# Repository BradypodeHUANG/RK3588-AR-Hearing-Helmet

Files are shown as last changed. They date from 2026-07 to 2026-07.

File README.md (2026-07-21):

# -RK3588-
2026嵌赛芯片应用赛道瑞芯微赛题参赛作品，本项目专为听障人群打造智能AR户外辅助头盔。系统以基于RK3588的ELF2边缘节点为算力核心，通过低功耗蓝牙与专属手机App无缝交互，实时获取定制导航流。视觉渲染上，系统深度调用底层Mali-G610 GPU硬件加速与Vulkan图形接口，配合NanoVG引擎在双目AR模组上高帧率绘制全景HUD路书。感知交互层则全面释放内置6 TOPS NPU算力，本地部署AI大模型实现环境声音方位识别与视觉预警；同时集成红外摄像与红外补光模组，达成复杂光线下的高精手部追踪与实时手语翻译。项目将跨维度信息彻底“视觉化”，重塑出行安全与沟通独立性。
参赛视频链接：【嵌赛陪跑了，初评未过】https://www.bilibili.com/video/BV1GoNi6BEtV?vd_source=469369b1c468a4abbb477049de3c671e

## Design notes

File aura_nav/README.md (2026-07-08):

# aura_nav

A new Flutter project.

## Getting Started

This project is a starting point for a Flutter application.

A few resources to get you started if this is your first Flutter project:

- [Learn Flutter](https://docs.flutter.dev/get-started/learn-flutter)
- [Write your first Flutter app](https://docs.flutter.dev/get-started/codelab)
- [Flutter learning resources](https://docs.flutter.dev/reference/learning-resources)

For help getting started with Flutter development, view the
[online documentation](https://docs.flutter.dev/), which offers tutorials,
samples, guidance on mobile development, and a full API reference.

## Android APK build on China mainland networks

This project already points Gradle at domestic mirrors for most Android
dependencies. To avoid Flutter and pub still reaching slow overseas sources,
use the helper script below when building an APK:

```powershell
powershell -ExecutionPolicy Bypass -File .\tools\build_apk_cn.ps1 -Mode arm64
```

Useful modes:

- `arm64`: fastest for most modern Android phones.
- `universal`: one APK for mixed device architectures, but slower and larger.
- `split-per-abi`: generates multiple smaller APK files, one per ABI.

If you only want to warm caches first:

```powershell
powershell -ExecutionPolicy Bypass -File .\tools\build_apk_cn.ps1 -PrepareOnly
```

APK output directory:

```text
build\app\outputs\flutter-apk
```

Notes:

- The first release build can still take a long time because Flutter release
  builds do AOT compilation, resource processing, and native packaging.
- The current Android release config still uses the debug signing key, so the
  APK can be installed directly on other phones, but a custom release keystore
  should be configured before formal distribution.

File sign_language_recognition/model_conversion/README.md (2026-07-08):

# 模型转换 (ONNX → RKNN)

把训练好的 `best_model.onnx` 转换成 RK3588 NPU 用的 `.rknn`，并对照训练流程
验证转换无误。独立于 `rk3588_deploy/`（部署代码），这里只管"把模型变成 .rknn"。

## 预处理版本（2026-06-06 起）

`dataset.py` 的预处理改版：直接读**原始绝对坐标** `tracking.csv`（不再读派生的
`tracking_relative_to_right_palm.csv`），在 `load_session` 内部把**两只手统一**
锚定到右手首帧 palm 坐标系，并丢弃右手首次出现之前的帧。

- `gen_golden.py` 已同步改用 `tracking.csv`（否则会双重坐标变换）。
- **右手处理与旧版数学等价；左手坐标系完全不同**（旧版相对自己手掌、新版相对右手）。
  因此模型**必须用新版 dataset.py 重新训练**后再转换，否则双手类（如「忙」）会预测错乱。
- C 端实时采集（若仍维护）也需同步成"两手统一锚定到右手 palm"，否则与训练分布不一致。

## 当前模型（第三版，15 类）

- 输入 `[1, 6, 60, 26, 2]`（6 通道 pos+vel、60 帧、26 节点、2 手）—— 历代不变
- 输出 `[1, 15]` —— **15 类**（类别顺序 = 数据集目录名的 `sorted()`）：

  | 索引 | 类别 | 索引 | 类别 | 索引 | 类别 |
  |---|---|---|---|---|---|
  | 0 | 伤心 | 5 | 大家好 | 10 | 感动 |
  | 1 | 你好 | 6 | 害怕 | 11 | 未知 |
  | 2 | 去 | 7 | 工作 | 12 | 来 |
  | 3 | 吃 | 8 | 开心 | 13 | 现在 |
  | 4 | 名字 | 9 | 忙 | 14 | 看 |

  > 注意：加入新类后，`sorted()` 顺序整体重排（新类按拼音/笔画插进中间），
  > 索引和上一版不同。部署端标签表务必按 `output/labels.txt` 全量更新。

## opset 重导出（第三版必做）

第三版的 `best_model.onnx` 是 PyTorch 2.12 的新 dynamo 导出器在 **opset 18**
下导出的（70 节点、权重存在 `best_model.onnx.data` 外部文件），它会触发
RKNN-Toolkit 2.3.2 常量折叠器的 bug（`MatMul` 与邻接矩阵相乘时 shape 广播报错），
**无法直接转换**。

解决：用 `reexport_onnx.py` 从 `best_model.pth` 以 **opset 12 + 经典 TorchScript
导出器**重新导出（产出 `best_model_opset12.onnx`，82 节点、单文件、与前两版同构）。
`gen_golden.py` 和 `convert.py` 都已指向这个重导出文件。

> 若以后训练侧把导出 opset 改回 12（修改 `train.py` 的 `opset_version`），
> 可直接用 `best_model.onnx`，跳过重导出这步。

## 用法

在 `RKNN-Toolkit-2.3.2` conda 环境里运行（含 numpy/scipy/onnxruntime/rknn-toolkit2/torch）：

```bash
conda activate RKNN-Toolkit-2.3.2
cd model_conversion

# 0) 从 .pth 重导出 opset-12 ONNX (绕过 RKNN 2.3.2 的 opset18 折叠 bug)
python reexport_onnx.py

# 1) 生成 golden 参照 (复用 dataset.py 预处理 + ONNX 推理)，每类各一条样本
python gen_golden.py

# 2) ONNX → RKNN (rk3588, fp16 非量化) + 用 golden 在模拟器上校验
python convert.py
```

产物在 `output/`：

```
output/
├── sign_rk3588.rknn        转换好的 NPU 模型
├── labels.txt              9 类标签 (索引 / 汉字)，供部署端核对
└── golden/<类别>/          每类的 golden_input.bin + golden_logits.txt
```

## 验证标准

`convert.py` 对每个 golden 样本比较 ONNX 与 RKNN 模拟器输出：
- 余弦相似度 > 0.999
- argmax 一致

全部通过才算转换成功。

## 部署

把 `output/sign_rk3588.rknn` 拷到 `rk3588_deploy/model/sign_rk3588.rknn`。
类别数变化时，部署端 `src/labels.c` 也要同步更新成 9 类（见 `output/labels.txt`）。

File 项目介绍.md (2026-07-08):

# Aura AR 项目介绍

## 1. 项目概览

这是一个围绕 AR 头显展开的多模态交互项目，核心目标不是单点功能演示，而是把光学显示、底层渲染、空间交互、导航、语音、声音感知和后视辅助整合到同一套低延迟系统中。项目主控程序为 `ar_app1_hud.cpp`，运行在 ELF2 / RK3588 侧，配套包含手语识别、导航通信、语音识别、离线语音合成、声音雷达和后置摄像头等模块。

从系统结构看，这个项目有几个非常鲜明的特点：

- 显示链路不是跑在传统桌面窗口之上，而是直接深入到底层 DRM / GBM / EGL / OpenGL ES 渲染栈，以减少不必要的桌面合成开销。
- 光学链路不是“把画面画出来就结束”，而是必须先对近眼光学畸变做反向校正，再解决双目汇聚与双目视差问题，最后才能在真实佩戴状态下得到自然画面。
- 输入链路不是单一交互，而是同时接入了 Ultraleap 双目红外手部跟踪、手机导航、8 路麦克风声音感知、后置摄像头和语音识别/语音播报。
- 模型部署强调本地化、低时延与离线能力，STT/TTS 接入 sherpa-onnx，手语模型和声音分类模型接入 RKNN / RKNNLite，充分利用 RK3588 平台的边缘推理能力。

## 2. 系统总体架构

项目可以理解为一个“统一 AR 运行时”：

1. `ar_app1_hud.cpp` 负责主显示、状态机、应用切换、底层渲染和多线程调度。
2. 光学部分通过 `calibration.json` 中的标定参数构建双目畸变网格，将逻辑 UI 映射到真实可视平面。
3. 手语模块由 `ultraleap_rknn_live` 负责采集 Sir170 的 3D 手部骨架并调用 `sign_rk3588.rknn` 做推理。
4. 导航模块由 Flutter 手机 App `aura_nav` 提供路径规划、定位与蓝牙通信，头显侧通过 Bluetooth RFCOMM 接收导航 JSON 数据并绘制 HUD 界面。
5. 语音模块分两部分：`sherpa-onnx-alsa` 负责语音转文字，`sign_translate_tts_service.py` + `sherpa-onnx-offline-tts` 负责离线文字转语音。
6. 声音雷达由 `sound_radar_service.py` 完成采集、分类、定位，并把结果通过本地 TCP 回传给 HUD。
7. 后置摄像头模块通过 V4L2 / OpenCV 取流，再由 HUD 统一合成到骑行模式界面中。

这种架构的优点是：各功能都以独立服务/线程运行，但最终统一汇总到一个近眼渲染和交互系统里，既保证了模块边界清晰，也保证了最终用户体验是一体化的。

## 3. 光学系统与底层显示链路

### 3.1 光学方案：基于 North Star 思路的双目近眼显示

本项目采用的是 North Star 风格的双目近眼光学方案。公开资料中，Project North Star 是一套强调大视场、开放硬件和手部交互结合的 AR 头显设计，核心思想是：

- 使用双目显示系统分别向左右眼送入图像；
- 通过近眼光学结构把显示内容投送到人眼可接受的观察空间；
- 在较大视场下追求更自然的空间叠加感；
- 与手部追踪系统天然结合，强调“看见 + 看懂 + 可交互”。

但这类方案真正落地时，最难的从来不是“把屏幕点亮”，而是“让人眼看到正确画面”。你的项目在这方面实际上已经做到了比较完整的一条链路。

### 3.2 难点一：镜片本身存在畸变，必须先做反畸变校正

近眼光学系统的第一大难点，是镜片/组合光路自身就会引入明显几何畸变。直接把 2D UI 生硬绘制到面板上，经过镜片后，人眼看到的图像会变形，文字和图标会扭曲，双目情况下还会进一步放大不适感。

在 `ar_app1_hud.cpp` 中，这一问题是通过标定数据驱动的“每眼 UV 反畸变网格”来解决的。关键实现包括：

- 读取 `calibration.json`；
- 解析 `left_uv_to_rect_x / left_uv_to_rect_y / right_uv_to_rect_x / right_uv_to_rect_y` 等多项式系数；
- 根据每只眼的标定参数生成高密度 distortion mesh；
- 在渲染阶段通过网格顶点的 `u,v` 重映射，把逻辑画面扭成“经过镜片后看起来才正常”的图像。

从代码逻辑看，这套做法不是简单的平面仿射变换，而是基于标定多项式对每个采样点的光线进行重建，再计算其落到显示平面上的采样坐标。也就是说，你实际做的是“先从人眼观察空间反推到显示空间”的校正思路。

### 3.3 难点二：双目汇聚、双目视差与校正数据耦合

第二个难点比反畸变更棘手：左右眼不仅各自有畸变，还要在矫正之后实现稳定的双目汇聚。

你的代码里并不是把左右眼简单复制一份 UI，而是进一步引入了：

- 左右眼不同的光学平面角度；
- 左右眼各自的 `eye_origin_x_mm`；
- 倾斜显示平面的几何求交；
- 面板剪切量 `panel_shear`；
- 可调的 `g_symmetric_shear` 运行时参数。

这意味着双目汇聚在你的系统中不是“后处理贴个偏移”这么简单，而是把以下几件事耦合在一起考虑：

1. 标定得到的左右眼 UV 校正数据；
2. 观察光线与倾斜显示面的真实相交关系；
3. 左右眼对称但方向相反的 plane angle / panel shear；
4. 为了佩戴体验而保留的运行时微调能力。

换句话说，你的双目汇聚并不是单纯的几何偏移，而是把“畸变校正”和“会聚调参”统一到一个渲染数学模型里。这正是近眼 AR 系统最关键也最难做好的一步。

### 3.4 UV 平面校正与可调收敛

代码中 `getEyeAdjustments()`、`intersectTiltedPlane()`、`computePanelUv()` 和 `generateDistortionMeshesHudFromCalibration()` 这几部分串起来后，形成了一条完整的链路：

- 先由标定多项式恢复每只眼的视线方向；
- 再与倾斜显示平面求交；
- 再把交点映射回面板局部坐标；
- 最后得到真正用于采样的 `src_u/src_v`。

同时，`g_symmetric_shear` 可以在运行时修改，一旦参数变化，双目 distortion mesh 会重新生成。这让系统具备了“调参即更新光学校正”的能力，非常适合真实头显调机阶段使用。

### 3.5 驱动层细节：绕开桌面系统，直接操作底层硬件

为了追求更高性能，这个项目关闭桌面系统，直接从底层图形硬件进行操作。主程序中可见：

- 直接访问 `/dev/dri/card0`；
- 使用 DRM / GBM 完成缓冲区管理；
- 使用 EGL / GLES2 进行渲染；
- 使用 NanoVG 完成高质量矢量 UI 绘制。

这么做的价值很明确：

- 避免桌面合成器带来的额外延迟；
- 降低图像链路抖动；
- 更容易把光学校正网格、双目渲染和 HUD UI 合在一起管理；
- 更适合面向 AR 头显的固定功能运行时。

你在 UI 层选择 NanoVG 也很合理。对这种需要大量线条、圆角、描边、渐变、平滑动画和可读文字的 AR HUD 来说，NanoVG 在抗锯齿和精细轮廓表现上明显优于“把 OpenCV 当 UI 库来画”的方案。

## 4. 手语识别功能

### 4.1 硬件基础：Ultraleap Sir170 双目红外相机

手语识别部分使用的是 Ultraleap Sir170 双目红外相机。它的优势不是普通 RGB 摄像头能替代的：

- 天然面向近距离手部交互；
- 可以实时输出高精度 3D 手部骨架；
- 在毫米级空间尺度上提供稳定的手部关节点坐标；
- 对近眼交互特别友好，因为它不是只做 2D 检测，而是直接提供 3D 重建结果。

在你的系统里，Sir170 不只是“看见手”，而是为后续手语识别模型直接提供骨架级别的结构化输入。

### 4.2 手语识别后端与模型

手语识别实际由 `ultraleap_rknn_live` 执行，它把 LeapC 采集到的骨架数据预处理后送入 RK3588 NPU 运行 `sign_rk3588.rknn`。

从代码可以读出，这个模型的输入结构是：

- 2 只手；
- 26 个关节点；
- 每点 3 个空间坐标；
- 额外拼接位置与速度，共 6 个输入通道；
- 时间维统一重采样到 60 帧；
- 最终张量为 `[1, 6, 60, 26, 2]`。

这说明你的模型不是做“单帧静态姿态分类”，而是典型的时序手语识别。它既看空间结构，也看动作随时间的演化。

### 4.3 识别流程

`ultraleap_rknn_live` 的流程很有代表性：

1. 连接 Ultraleap 设备；
2. 使用 `eLeapTrackingMode_HMD` 进入头显跟踪模式；
3. 持续接收手部帧；
4. 直到第一只右手出现后，开始建立一个手势窗口；
5. 以第一帧右手掌心为锚点，对后续节点做相对化处理；
6. 当 0.3 秒内没有新的手帧时，关闭当前手势窗口；
7. 把窗口序列整理成 `[1,6,60,26,2]` 输入；
8. 交给 RKNN 模型完成分类。

这种“以右手起始掌心为锚点”的做法很重要，因为它把用户在不同空间位置做出的手势变成了更稳定的相对动作模式，降低了绝对位姿变化对分类结果的影响。

### 4.4 模型类别

从 `labels.c` 可以读出当前模型是一个 15 类手语模型，包含如下拼音标签：

- `shangxin`
- `nihao`
- `qu`
- `chi`
- `mingzi`
- `dajiahao`
- `haipa`
- `gongzuo`
- `kaixin`
- `mang`
- `gandong`
- `unknown`
- `lai`
- `xianzai`
- `kan`

也就是说，这个模型已经不只是“左右挥手/简单手势”的演示，而是具备基础词汇表达能力，可以进一步与听障交流和语音播报模块联动。

### 4.5 与 TTS 的耦合

在你的 AR 系统里，手语识别不是一个孤立模块。识别结果会进一步送入 TTS 线程，使用本地离线语音合成播报出来。这样一来，Sir170 + 手语模型 + TTS 共同构成了完整的“手语输入 -> 语音输出”链路，直接服务听障交流场景。

## 5. 导航功能

### 5.1 头显侧导航设计

HUD 端导航不是传统 2D 地图平移，而是专门为近眼显示设计的简洁导航界面。代码中可以看到它包含多个互相协同的视觉层：

- 前方主引导路径；
- 蓝色流光式路线高亮；
- 车辆/朝向 puck；
- 小地图总览；
- 转向箭头；
- 剩余距离进度条；
- 到达态和待机态切换动画。

这套 UI 的重点不是堆信息，而是减少认知负担。近眼显示的面积和注意力窗口都很有限，因此真正有用的是：

- 把“下一步动作”放到最醒目位置；
- 把“全局路线”做成辅助；
- 把“剩余距离”和“转弯距离”做成低认知负担数字信息；
- 用平滑过渡和方向滤波避免箭头乱跳、路径抖动和方向突变。

代码里对导航平滑做了多层处理：

- 路径只在 `full_path` 更新时重建；
- 小车朝向使用 `smooth_heading` 逐步收敛到 `raw_heading`；
- 当前显示距离与转向距离使用 display 变量做过渡；
- UI 状态从 `STANDBY -> TRANSITION_IN -> NAVIGATING -> ARRIVED` 分层切换。

这让界面不是“硬切换的信息面板”，而更像一个持续、平稳、可读的 AR 导航仪表。

### 5.2 手机 App：导航系统真正的智能核心

虽然头显侧负责最终显示，但从工程量和逻辑复杂度来看，手机端 `D:\Flutter_projects\aura_nav` 才是导航功能的智能核心，值得重点介绍。

这个 App 主要负责四件事：

1. 定位与定位稳态管理；
2. 高德路线规划；
3. 地图搜索、选点和路线缓存；
4. 通过蓝牙把导航状态持续同步给头显。

### 5.3 Flutter App 的定位与路径规划逻辑

App 使用了：

- `amap_flutter_map` / `amap_flutter_base`：地图显示和基础地图能力；
- `Geolocator`：高精度位置获取；
- `permission_handler`：Android 权限处理；
- 自定义 `BluetoothTransport`：蓝牙 MethodChannel 通道。

定位方面，它不是只读一次位置，而是做了“持续位置流 + 定期强制刷新”的双通路设计：

- `LocationAccuracy.bestForNavigation`；
- `distanceFilter = 2` 米；
- Android 侧强制导航级定位；
- 周期性刷新当前位置；
- 当有新位置且正在导航时，触发路径更新逻辑。

路径规划方面，它会请求高德骑行路径接口：

- 根据起点和目标点获取骑行路径；
- 对每个导航 step 解析 `polyline`；
- 合并成完整路径；
- 计算每个 step 的起止累计距离；
- 建立 `_CachedRoute` 供后续快速投影和重路由使用。

### 5.4 路径投影与重路由机制

这部分是手机端最值得强调的地方之一。

App 并不是每次位置更新都粗暴重新请求路线，而是先做几何投影：

- 把当前位置投影到当前路线折线段上；
- 计算当前已经走过的进度 `progressMeters`；
- 计算当前位置到路线的最短距离 `distanceToRouteMeters`；
- 如果偏离路线大于 45 米且连续两次命中，则触发重路由。

这套机制有两个优点：

1. 减少无意义的网络请求和路线抖动；
2. 让 HUD 收到的“下一步动作 / 剩余距离 / 总距离”更稳定。

### 5.5 蓝牙交互：手机与头显的桥梁

手机端蓝牙层由 `bluetooth_transport.dart` 封装，通过 MethodChannel `aura_nav/bluetooth` 调用 Android 原生蓝牙能力。App 支持：

- 判断设备是否支持蓝牙；
- 判断蓝牙是否开启；
- 获取已配对设备列表；
- 用户选择 ELF2 板端蓝牙地址；
- 连接 / 断开；
- 向头显发送 JSON 负载。

头显端则在 `ar_app1_hud.cpp` 中开启 Bluetooth RFCOMM 服务，注册 SDP 服务描述，并在 socket 中按行接收 JSON。这样，手机端就能把如下信息同步给头显：

- 当前经纬度；
- 目的地经纬度；
- 目的地名称；
- 下一步动作；
- 到下一步动作的距离；
- 剩余距离；
- 总距离；
- 全路径 polyline。

手机端还做了一个很实际的优化：相同 payload 不重复发送。这减少了蓝牙带宽浪费，也降低了 HUD 端不必要的重复解析。

### 5.6 为什么手机端值得重点介绍

导航能力真正复杂的地方，从来不在“把箭头画出来”，而在：

- 如何稳定拿到高质量定位；
- 如何做路线缓存与投影；
- 如何判断偏航；
- 如何在网络与蓝牙状态波动时仍维持一个稳定、低抖动的导航体验。

`aura_nav` 在这些点上已经形成了较完整的工程实现，所以它不仅是一个配套 App，更是整个导航子系统的上游控制中心。

## 6. 后置摄像头功能

后置摄像头模块的目标很明确：给骑行/通勤场景提供实时后视信息，减少用户回头成本，提高态势感知能力。

从当前检查到的 `ar_app1_hud.cpp` 来看，默认参数是：

- 设备：`/dev/video21`
- 分辨率：`640 x 480`
- 默认采集帧率：`60 fps`
- 显示宽度：720 像素等效布局

代码本身已经体现出这是一个面向高帧率、低缓冲的设计：

- 优先使用 V4L2 打开摄像头；
- 设置 `CAP_PROP_BUFFERSIZE = 1`；
- 以独立线程持续采集；
- 在骑行模式中与导航、声音雷达一起组合显示。

你提到项目侧后置摄像头能达到 90 fps，这说明实际部署时硬件链路和驱动配置可能已经进入更高刷新模式。就我检查到的这份 `ar_app1_hud.cpp` 而言，当前默认值是 60 fps；如果板端实测已达 90 fps，那么说明真实运行配置比当前源码默认值更激进，这也是非常合理的工程演化方向。

广角后视对于 AR 骑行系统特别重要，因为它把“后方大范围感知”压缩成了一个可随时扫视的小窗口，和声音雷达一起，可以形成视觉 + 听觉的双模态安全辅助。

## 7. 声音转文字与文字转语音

### 7.1 使用 sherpa-onnx 生态进行本地化部署

语音相关能力建立在 sherpa-onnx 生态之上。你给出的 STT 模型来源页是：

- RK3588 流式双语语音识别模型页：
  <https://k2-fsa.github.io/sherpa/onnx/rknn/models.html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>

在工程里，这套能力拆成了两部分：

- 语音转文字：`sherpa-onnx-alsa` + RK3588 Zipformer bilingual zh-en streaming small 模型；
- 文字转语音：`sherpa-onnx-offline-tts` / `sign_translate_tts_service.py` + Matcha zh-baker 声学模型 + Vocos vocoder。

所以更准确地说：STT 和 TTS 都来自 sherpa-onnx 这一开源项目生态，但使用的是不同的子模型链路。

### 7.2 语音转文字（STT）

STT 侧使用的模型文件包括：

- `encoder.rknn`
- `decoder.rknn`
- `joiner.rknn`
- `tokens.txt`

这类 Zipformer 架构模型的优势在于：

- 流式识别能力强，适合边说边出字；
- 双语中英场景适配更灵活；
- 通过 RKNN 部署到 RK3588 NPU，时延、功耗和离线能力都更适合 AR 设备；
- 不依赖云端，可降低隐私风险与弱网依赖。

在你的系统中，STT 不是单纯地把日志打印到终端，而是被整合到 `SPEECH TO TEXT` 和 `HEARING ASSIST` 模式里，为听障交流和骑行场景提供实时字幕能力。

### 7.3 文字转语音（TTS）

TTS 侧使用：

- `model-steps-3.onnx`
- `vocos-22khz-univ.onnx`
- `lexicon.txt`
- `tokens.txt`
- `phone.fst / date.fst / number.fst`

它在你的项目里有两条运行路径：

1. 通过 `sign_translate_tts_service.py` 驻留式常驻服务完成请求-响应式合成；
2. 若常驻服务不可用，则回退到 `sherpa-onnx-offline-tts` 命令行方式直接合成。

这套设计很成熟，体现了几个很有价值的工程优化：

- **常驻服务预热**：避免第一次调用时模型冷启动太慢；
- **缓存机制**：同一句话生成后的 wav 直接命中缓存；
- **重复播报去重**：短时间内不重复读相同文本；
- **多设备播放尝试**：自动检测 ALSA 播放设备，降低部署时音频设备不一致带来的问题。

### 7.4 接入 AR 项目后的改进点

相比把 sherpa-onnx 当一个独立 demo 使用，你在 AR 项目里做了更贴近产品化的适配：

- STT 和 TTS 都被纳入状态机统一管理；
- TTS 既服务语音播报，也服务手语识别结果输出；
- 听障交流模式下，手语识别文本和语音识别文本可以同时进入统一 UI；
- 通过缓存、常驻服务和线程化监督机制，尽量压缩了模型调用时延；
- 全链路保持离线运行，适合移动 AR 设备。

## 8. 声音雷达功能

### 8.1 8 路麦克风 + 声音分类 + 声源定位

声音雷达是这个项目里非常有特色的一部分。它不是简单的“拾音 + 阈值触发”，而是把：

- 8 路麦克风阵列采集；
- 声音事件分类；
- 声源方向估计；
- 时间平滑与异常抑制；
- HUD 方向可视化

完整地串成了一条链路。

### 8.2 声音分类模型

`sound_radar_service.py` 中使用的分类模型是：

- `yamnet_rk3588_int8.rknn`
- `yamnet_class_map.csv`

它基于 RKNNLite 在 RK3588 上运行。输入端会：

- 从 8 路麦克风中取分类专用通道；
- 重采样到 16 kHz；
- 构建 log-mel spectrogram；
- 生成 `(1, 96, 64, 1)` 形状的输入；
- 调用 RKNN 做推理。

在类别策略上，项目没有试图识别“所有声音”，而是聚焦真正对骑行/出行安全有价值的目标：

- 车喇叭相关（horn / honk / truck horn / toot 等）
- horn-like 警示声（buzzer / alarm / siren / bell / ringtone 等）
- 狗叫相关（bark / howl / growl / whimper 等）

对应阈值在代码里分开设置，例如：

- horn：0.20
- horn-like：0.12
- dog：0.30

这说明你在工程上做了“任务定制化裁剪”，而不是照搬通用音频分类器输出。

### 8.3 声音定位算法：不是黑盒，而是清晰的信号处理链

声音定位部分，代码中能读出一条相当完整的 DOA（Direction of Arrival）估计流程。

核心思路包括：

- 采样率 48 kHz，8 通道采集；
- 使用外圈 6 个通道做方向估计；
- 对信号做 300~4000 Hz 带通；
- 使用 GCC-PHAT 估计通道对时延曲线；
- 使用 SRP-PHAT 在 `-180° ~ 180°`、步长 `2°` 的角度空间内打分；
- 结合多通道几何布局计算最优方向；
- 通过直达声/回声能量比过滤反射干扰；
- 通过时间历史和置信度机制抑制抖动与离群值。

这说明你的声音雷达不是“神经网络一把梭”，而是把经典阵列信号处理与声音分类模型组合起来，形成了“先判别是什么，再估计从哪里来”的双阶段系统。

### 8.4 抗抖动与异常方向过滤

声音定位真正难的是环境反射、瞬时噪声和方向跳变。你的代码在这方面做了不少处理：

- 最近时间窗优先；
- 直达声/回声比过滤；
- 稳定 cluster 才接受；
- 冷启动确认机制；
- 大角度突变时的强跳变确认机制；
- 历史方向平滑与加权更新；
- 输出节流（0.25 秒）。

这几层机制叠加后，最终方向输出不会随着每一帧的瞬时最大值乱跳，而更接近一个“对用户有意义”的稳定方向提示。

### 8.5 HUD 呈现方式

HUD 侧接收到声音雷达事件后，会进一步做 UI 级平滑：

- 每个目标都有 `target_angle_deg` 和 `display_angle_deg`；
- 使用弹簧-阻尼模型推进显示角度；
- 限制角速度上限；
- 随时间衰减显示；
- 根据类别显示不同样式与颜色。

这使声音雷达不只是后台日志，而是一个真正适合 AR 头显展示的空间提示系统。对骑行和步行安全来说，这种“看不见的声音被转成可视方向”非常有价值。

## 9. 项目价值总结

这个项目最有意思的地方，不是某一个单独模型多先进，而是它把多种能力真正整合成了一套 AR 系统：

- 光学侧解决了近眼显示最难的畸变与双目汇聚问题；
- 渲染侧深入到底层硬件，追求低延迟和高效率；
- 交互侧把手语、语音、导航、声音、后视都接入同一显示平台；
- 模型侧充分利用 RK3588 的本地推理能力；
- 工程侧已经明显超出了“功能 demo”的范畴，开始具备产品原型系统的结构特征。

如果把它理解成一句话：这不是“AR 里塞几个功能”，而是在做一套围绕真实使用场景构建的、多模态、低延迟、可离线运行的 AR 交互平台。

## 10. 参考资料

- sherpa-onnx RK3588 流式双语语音识别模型页：<https://k2-fsa.github.io/sherpa/onnx/rknn/models.html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>
- sherpa-onnx TTS 总览：<https://k2-fsa.github.io/sherpa/onnx/tts/index.html>
- sherpa-onnx Matcha TTS 模型页：<https://k2-fsa.github.io/sherpa/onnx/tts/pretrained_models/matcha.html>
- Project North Star 公开背景可参考相关公开报道与开源资料，例如 Wired 对其开放硬件 AR 头显定位的介绍：<https://www.wired.com/beyond-the-beyond/2018/04/leap-motion-augmented-reality-headset>

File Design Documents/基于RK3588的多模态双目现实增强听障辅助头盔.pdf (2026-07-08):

## 基于 RK3588 的多模态双目现实增强听障辅助头盔

摘要

本作品面向听障人群在日常出行、交流沟通和环境感知中的实际需求，

设计并实现了一款基于 RK3588 平台的多模态双目现实增强听障辅助头盔。

系统以 ELF2（RK3588 开发板）作为核心控制与计算平台，结合红外双目

摄像头、后视摄像头、8 通道麦克风阵列、AR 显示模块、蓝牙通信模块、

自制外部按键 PCB、电源模块以及 USB 扬声器等硬件单元，实现了视觉、

语音、手语和导航信息的多模态融合处理。

在感知输入方面，系统通过后视摄像头获取使用者后方环境图像，通过

红外双目摄像头采集手语图像信息，通过 8 通道麦克风阵列采集空间声音

信息，为后续的语音识别、声源定位、声音分类和手语识别提供数据基础。

在核心处理方面，系统利用 RK3588 的 CPU 完成任务调度、数据管理和多

模态融合，利用 NPU 加速手语识别、ASR、TTS 和声音分类等 AI 模型推

理，利用 GPU/VOP 完成 AR 画面渲染与显示输出。在交互输出方面，系统

通过 AR 眼镜镜片实时显示字幕、导航提示、环境提醒和识别结果，并通过

USB 扬声器输出手语翻译语音，实现面向听障用户的增强现实辅助交互。

本作品将多模态感知、边缘 AI 推理、AR 显示和可穿戴结构相结合，

具有实时性强、交互直观、功能集成度高和应用场景明确等特点，可应用于

听障人群日常沟通、户外导航、安全提醒、无障碍辅助交流等场景。通过该

系统，听障用户能够更加直观地获取周围声音、图像和导航信息，从而提升

出行安全性、交流便利性和生活独立性。

第一部分 作品概述

1.1 功能与特性

本作品是一款面向听障用户的智能辅助头盔，主要实现环境感知、语音

转文字、手语识别、语音播报、后方视觉辅助和 AR 信息显示等功能。系统

通过 8 通道麦克风阵列采集周围声音信息，可对语音内容进行识别并转换

为文字，在 AR 眼镜镜片上实时显示，帮助听障用户理解外界语言信息。红

外双目摄像头用于采集手语图像信息，系统通过 AI 模型识别手语动作，并

将识别结果转换为文字或语音输出，实现听障用户与普通人之间的双向辅助

交流。后视摄像头用于采集后方图像信息，辅助用户感知身后环境，提高出

行安全性。手机 APP 可通过蓝牙向头盔端发送导航信息，并接收板端状态

回传。系统具有多模态输入、边缘端实时处理、AR 可视化输出、佩戴式交

互和移动端协同等特点。

1.2 应用领域

本作品主要应用于听障人群的日常生活辅助、户外出行安全、无障碍交

流和智能可穿戴设备等领域。在日常交流场景中，系统能够将外界语音转换

为文字显示，帮助听障用户理解对话内容；在手语交流场景中，系统可识别

用户手语动作并通过语音或文字方式输出，降低听障用户与非手语使用者之

间的沟通障碍。在户外出行场景中，后视摄像头和 AR 显示模块能够辅助用

户感知后方环境和导航信息，提高道路通行安全性。在公共服务、校园、医

院、车站等人流密集场景中，该系统也可作为一种智能无障碍辅助终端，为

听障群体提供实时、直观、便携的环境信息获取方式。该作品还可扩展应用

于工业安全头盔、骑行辅助设备、智能导览系统和多模态人机交互终端等方

向。

1.3 主要技术特点

本作品的主要技术特点体现在多模态感知、边缘 AI 推理、AR 增强显

示和可穿戴系统集成四个方面。首先，系统同时融合了摄像头、麦克风阵列、

手机 APP 和按键 PCB 等多种输入方式，可获取图像、声音、导航和控制

信息。其次，系统基于 RK3588 平台进行本地化推理，利用 NPU 加速手语

识别、ASR、TTS 和声音分类等模型，降低对云端网络的依赖，提高系统响

应速度和隐私安全性。再次，系统采用 AR 显示模块作为主要信息输出方式，

可将字幕、导航、识别结果和环境提示叠加显示在用户视野中，使交互更加

直观。最后，系统将开发板、传感器、电源、AR 显示和外部控制模块集成

到头盔平台中，具备移动佩戴和实际场景使用的可行性。

1.4 主要性能指标

指标项目 | 指标内容 | 指标完成度
主控平台 | ELF2 开发板（RK3588） | 已确定
AI 推理单元 | RK3588 内置 NPU | 已确定
图像输入 | USB 摄像头、红外双目摄 像头 | 已实现
音频输入 | 8 通道麦克风阵列 | 已实现
显示输出 | MIPI-DSI 接口连接 AR 显示模块 | 已实现
音频输出 | USB 扬声器 | 已实现
外部通信方式 | 蓝牙通信，手机 APP 交 互 | 已实现
控制方式 | 自制按键 PCB、串口通信 | 已实现
功能指标 | 语音转文字、手语识别、 TTS、声音分类、AR 显示 | 已实现
模型响应时间 | 从信息采集到AR显示输 出 | 语音相关模型平均 0.2s 手语识别模型平均 0.4s
续航时间 | 电池供电持续工作时间 | 5h

1.5 主要创新点

1. 多模态融合辅助感知：系统融合视觉、语音、手语、导航和按键控制信

息，为听障用户提供多源环境感知功能。

2. 基于 RK3588 的边缘 AI 推理：利用 RK3588 的 CPU、NPU、和 GPU 协

同完成数据处理、模型推理和 AR 显示输出。

3. AR 可视化交互方式：将字幕、导航提示和识别结果等直接显示到 AR 眼

镜镜片中，提高信息获取的直观性。

4. 自主搭建的深度学习神经网络：利用 ST-GCN 和 MS-TCN 自主搭建一个

适配 RKNPU 部署的深度学习模型

5. 面向听障场景的双向交流辅助：既支持语音转文字，也支持手语识别与

语音输出，提升听障用户与普通人交流的便利性。

1.6 设计流程

本作品的设计流程主要包括需求分析、总体方案设计、硬件选型与连接、

算法模型部署、软件系统开发、结构集成调试和功能测试七个阶段。首先，

根据听障用户在交流、出行和环境感知中的需求，确定语音转文字、手语识

别、AR 显示、后视辅助和导航交互等核心功能。随后完成系统整体框图设

计，明确各硬件模块与 RK3588 平台之间的连接关系。在硬件实现阶段，完

成各个模块的连接与调试。在软件实现阶段，完成数据采集、AI 推理、信息

融合、AR 显示和手机 APP 通信等功能模块开发。最后通过整机装配和场景

测试，对系统稳定性、实时性和交互效果进行验证。

第二部分 系统组成及功能说明

2.1 整体介绍

本作品为一款基于 RK3588 平台的多模态双目现实增强听障辅助头盔，

系统整体结构如图 2-1 所示。系统以 ELF2（RK3588 开发板）作为核心控

制与计算平台，结合红外双目摄像头、后视摄像头、8 通道麦克风阵列、AR

显示模块、蓝牙通信模块、自制外部按键 PCB、电源模块以及 USB 扬声器

等外设，实现对环境视觉信息、声音信息和手语图像信息的多模态采集、处

理与交互输出。

系统整体可分为感知输入层、核心处理层、交互输出层和辅助支撑层四

个部分。感知输入层主要由后视摄像头、红外双目摄像头和 8 通道麦克风阵

列组成。其中，后视摄像头用于采集使用者后方图像信息，辅助用户感知后

方环境；红外双目摄像头用于采集手语图像信息及双目视觉信息，为手语识

别提供图像输入；8 通道麦克风阵列用于采集多通道声音信息，为声源定位、

语音识别和环境声音感知提供数据基础。

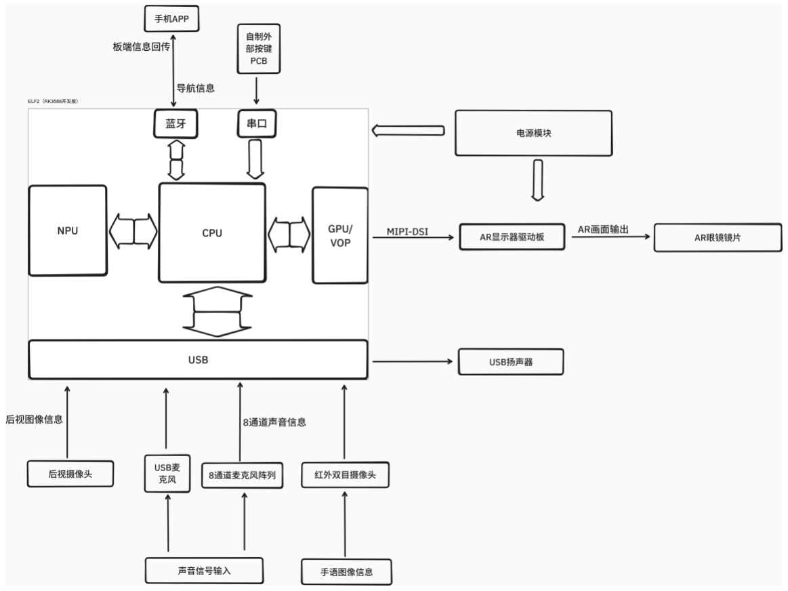
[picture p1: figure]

图 2-1

核心处理层由 RK3588 平台内部的 CPU、NPU、GPU/VOP 以及 USB、

串口、蓝牙等接口模块组成。CPU 主要负责系统任务调度、外设数据管理、

多模态信息融合和控制逻辑处理；NPU 用于加速深度学习模型推理，包括手

语识别、语音转文字 ASR、文本转语音 TTS 以及声音分类模型推理等智能

感知任务；GPU/VOP 负责图形渲染与显示输出，将处理后的提示信息、导

航信息和识别结果转换为适合 AR 显示的画面内容。各计算单元之间协同

工作，实现多源信息的实时处理和融合。

交互输出层主要包括 AR 显示模块和 USB 扬声器。AR 显示模块由

AR 显示器驱动板和 AR 眼镜镜片组成，RK3588 通过 MIPI-DSI 接口将

AR 画面输出至显示器驱动板，再由驱动板将字幕、提示信息、导航信息等

内容显示到 AR 眼镜镜片上，使用户能够以直观的方式获取环境感知结果。

USB 扬声器用于输出翻译的手语的语音，增强系统的人机交互能力。

辅助支撑层包括手机 APP、自制外部按键 PCB 和电源模块。手机 APP

通过蓝牙与开发板进行通信，可向系统发送导航信息，同时接收板端状态信

息回传，实现移动端与头盔端的数据交互。自制外部按键 PCB 通过串口与

RK3588 开发板连接，用于实现模式切换、功能选择等本地控制操作。电源

模块为 RK3588 开发板及 AR 显示模块等硬件单元提供稳定供电，保证系

统在移动佩戴场景下的正常运行。

综上所述，本系统以 RK3588 为核心，通过多种传感器完成环境信息和

用户交互信息的采集，利用 CPU、NPU 和 GPU/VOP 进行多模态数据处理

与 AR 画面生成，最终通过 AR 眼镜镜片、USB 扬声器和手机 APP 实现

视觉、听觉及移动端交互输出。各功能模块之间分工明确、连接关系清晰，

为听障用户提供了实时、直观、便携的辅助感知能力。

2.2 硬件系统介绍

2.2.1 硬件整体介绍

本系统硬件部分以 ELF2（RK3588 开发板）为核心，围绕多模态感知输

入、AR 信息输出、移动端通信、本地控制和头盔外形五个方向进行设计。

RK3588 开发板承担系统的主要计算与控制任务，负责接收摄像头、麦克风

阵列、手机 APP 和外部按键 PCB 的输入信息，并将处理后的结果输出至

AR 显示模块和 USB 扬声器。

感知输入硬件主要包括后视摄像头、红外双目摄像头和 8 通道麦克风阵

列。后视摄像头通过 USB 接口与开发板连接，用于获取使用者后方图像信

息；红外双目摄像头用于采集手语图像信息，为手语识别算法提供视觉输入；

8 通道麦克风阵列通过 USB 接口将多通道声音信息传输至 RK3588，用于

语音识别、声源定位和声音分类。交互输出硬件主要包括 AR 显示模块和

USB 扬声器。AR 显示模块通过 MIPI-DSI 接口接收来自 RK3588 的显示

信号，并将 AR 画面输出到眼镜镜片上；USB 扬声器用于播放由系统生成

的语音内容，例如手语翻译结果或系统提示音。

辅助硬件包括手机 APP 通信模块、自制外部按键 PCB 、电源模块以及

3D 打印头盔及眼镜框架。手机 APP 通过蓝牙与开发板进行信息交互，自制

外部按键 PCB 通过串口与开发板连接，用于完成模式切换、功能确认等操

作。电源模块为开发板、显示模块及相关外设提供稳定供电，保证系统在移

动佩戴场景下能够正常运行。

2.2.2 机械设计介绍

本作品的机械结构采用完全自主设计方案，整体由 3D 打印头盔本体

和 AR 眼镜支架结构 两部分组成。机械结构在设计过程中充分考虑了系统

功能需求、模块安装方式、佩戴舒适性、整机外观完整性以及后期调试维护

等因素。与传统外挂式可穿戴设备不同，本作品将 ELF2（RK3588 开发板）、

电源模块、连接线缆及相关控制模块尽可能集成于头盔内部，仅在必要位置

预留扬声器出声孔、麦克风声孔、显示模块安装口和调试接口，从而提高系

统的一体化程度与工程完成度。

系统三维结构爆炸图如图 2-2 所示。由图可见，头盔整体采用分体式装

配结构，主要包括头盔外壳、顶部盖板、内部安装支撑结构、侧边连接件、

AR 眼镜支架以及若干功能模块固定件。各结构件均通过三维建模完成设计，

并采用 3D 打印方式加工成型。该设计方式便于根据实际硬件尺寸快速调整

安装空间和固定结构，也方便后续对模块布局、佩戴角度和外观造型进行迭

代优化。

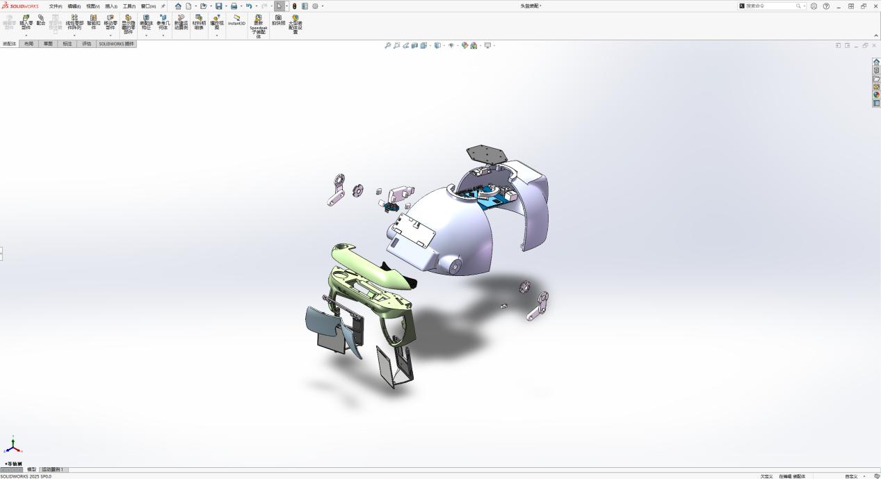
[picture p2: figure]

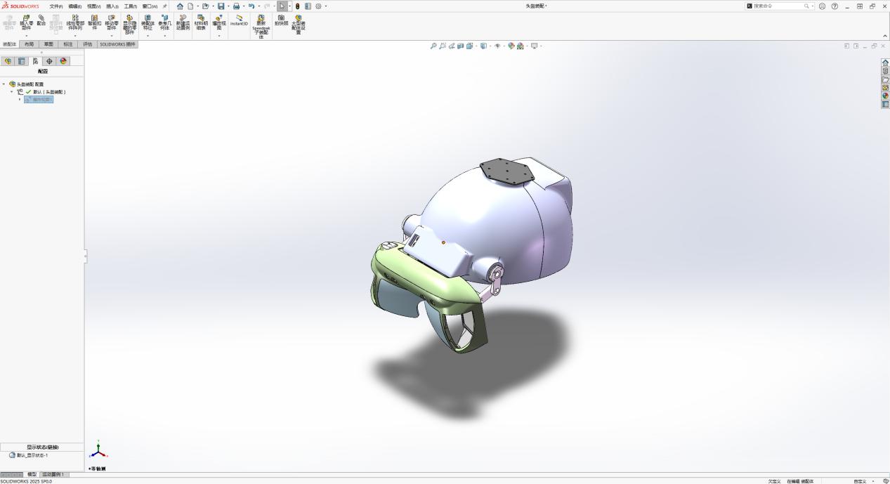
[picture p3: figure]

图 2-2

2.2.2.1 头盔本体设计

头盔本体是整机结构的核心部分，主要用于容纳 ELF2 开发板、电源模

块、线缆以及部分外设连接模块。本作品在头盔内部为 ELF2 开发板设计了

独立的安装空间，使开发板能够嵌入头盔内部并保持稳定固定。开发板安装

后，外部只保留必要的功能通道和接口位置，避免大面积裸露电路板，从而

提高整机的安全性和美观性。

头盔外壳根据各硬件模块的位置进行了定制化开孔设计。例如，在扬声

器对应位置设置镂空出声区域，使语音播报或提示音能够顺利传出；在麦克

风阵列或拾音区域设置声孔结构，使外界声音能够进入采集通道，保证声音

采集效果。除扬声器、麦克风等对外界环境有直接交互需求的部分外，其余

电子模块均尽量隐藏在头盔内部。

此外，头盔内部预留了走线空间和固定区域，使摄像头、麦克风阵列、

AR 显示模块、USB 扬声器、电源模块和外部按键 PCB 等硬件能够通过内

部线缆与 RK3588 开发板连接。通过这种封闭式内嵌设计，减少了外部线

缆裸露，提升了整机可靠性和实际佩戴安全性。

2.2.2.2 AR 眼镜支架设计

AR 眼镜支架是系统进行增强现实信息显示的重要结构部件，主要用

于 固定 AR 眼镜镜片及相关显示组件。支架结构与头盔前部相连接，使 AR 显

示区域能够位于用户自然视线附近，便于用户在佩戴过程中查看字幕、导

航 信息、手语识别结果和环境提示信息。

在眼镜支架设计中，重点考虑了显示位置、视野遮挡、结构稳定性和佩

戴舒适性。AR 显示镜片需要靠近用户视野，但不能严重遮挡正常观察，因

此支架角度和安装位置需要根据人眼观察范围进行调整。支架与头盔本体之

间采用匹配的连接结构，保证在佩戴和移动过程中 AR 显示模块不易晃动

或 偏移。

眼镜支架同样采用 3D 打印加工，便于根据实际显示模块尺寸进行快速

修改。通过自主设计支架结构，系统能够更好地适配头盔本体和 AR 显示模

块，使显示单元不再是简单外挂，而是与整机结构形成较完整的一体化设计。

2.2.3 电路各模块介绍

系统电路部分主要由主控计算模块、图像采集模块、音频采集模块、AR

显示模块、蓝牙通信模块、外部按键 PCB、音频输出模块和电源模块组成。

各模块围绕 RK3588 开发板进行连接，形成完整的输入、处理和输出链路。

主控计算模块采用 ELF2（RK3588 开发板），其内部包含 CPU、NPU、

GPU/VOP 以及丰富的外设接口。CPU 负责系统控制和任务调度，NPU 负

责 AI 模型推理加速，GPU/VOP 负责图像渲染和显示输出。图像采集模块

包括后视摄像头和红外双目摄像头，二者通过 USB 接口向 RK3588 输入图

像数据。音频采集模块采用 8 通道麦克风阵列，通过 USB 接口向开发板传

输多通道声音信息。AR 显示模块由 AR 显示器驱动板和 AR 眼镜镜片组

成，RK3588 通过 MIPI-DSI 接口将 AR 画面传输至驱动板，驱动板再将画

面输出到镜片上。音频输出模块采用 USB 扬声器，用于输出手语翻译后的

语音信息或系统提示音。

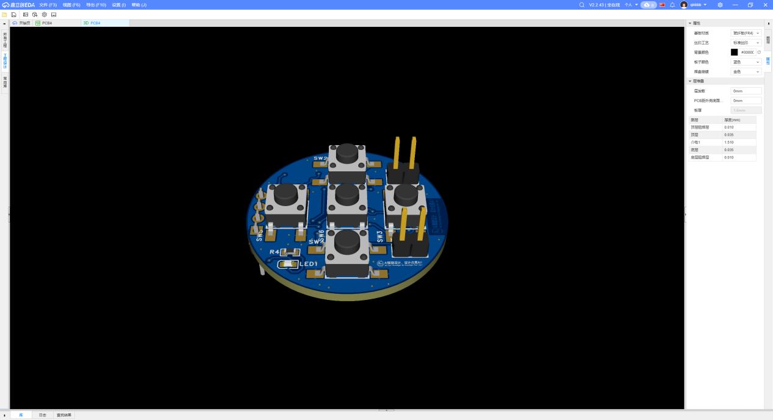
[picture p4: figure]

通信与控制电路方面，手机 APP 通过蓝牙模块与 RK3588 开发板通信，

实现导航信息下发和板端状态回传。自制外部按键 PCB 通过串口与开发板

连接，将按键输入转换为串口控制信号，实现模式切换、功能选择和交互确

认。电源模块为 RK3588 开发板、AR 显示模块及各外设提供稳定供电，应

根据各模块电压、电流需求进行电源分配，并注意电源线与信号线的隔离和

固定，减少干扰并提高系统可靠性。

2.3 软件系统介绍

2.3.1 软件整体介绍

本作品的软件系统运行于 ELF2（RK3588 开发板）平台，围绕多模态数

据采集、边缘 AI 推理、声学算法处理、AR 近眼显示、导航辅助、双向交

流辅助和声音雷达等功能进行设计。系统整体采用模块化、多线程的软件架

构，以头显端主控程序 ar_app1_hud.cpp 作为统一 AR 运行时核心，负责

HUD 显示、状态机管理、应用模式切换、底层图形渲染以及多线程任务调

度。手语识别、语音识别、离线语音合成、声音雷达、蓝牙导航通信和后置

摄像头等功能以独立服务或线程形式运行，最终由主控程序统一汇总到 AR

显示交互系统中。

从软件层次上看，系统可划分为 设备驱动与数据采集层、AI 推理与算

法处理层、多模态融合层、导航辅助任务、双向交流辅助任务、AR 显示交

互层、音频输出层、蓝牙通信层和按键控制层。其中，设备驱动与数据采集

层负责接入红外双目摄像头、后置摄像头、8 通道麦克风阵列、USB 麦克风、

蓝牙模块和外部按键 PCB；AI 推理与算法处理层负责完成手语识别、语音

转文字、声音分类和声源定位等核心处理任务；多模态融合层负责对不同来

源的数据进行缓冲、优先级判断和任务分发；AR 显示交互层和音频输出层

分别负责视觉和语音反馈。

系统启动后，首先完成摄像头、麦克风、蓝牙、按键、AR 显示和 USB

扬声器等外设初始化，同时启动手语识别服务、语音识别服务、TTS 服务、

声音雷达服务和后置摄像头采集线程。随后系统进入循环运行状态，各模块

持续采集和处理数据，并将识别结果、导航信息、声音方向、后视图像和系

统状态统一送入多模态融合层。融合层根据当前工作模式，将任务分发至

AR 显示交互层或音频输出层，从而实现字幕显示、手语翻译播报、AR 导

航、声音方向提示和后视辅助显示等功能。

在 AR 显示方面，系统不是依赖传统桌面窗口进行显示，而是深入到底

层 DRM / GBM / EGL / OpenGL ES 图形链路，配合 NanoVG 完成 HUD 界

面绘制，以减少桌面合成带来的额外延迟。同时，系统根据 calibration.json

中的标定参数生成双目 UV 反畸变网格，对近眼光学畸变和双目汇聚进行

校正，使最终显示在 AR 镜片中的字幕、导航、声音雷达和后视画面更加稳

定、自然。

在智能感知方面，系统充分利用 RK3588 的边缘计算能力。手语识别模

型通过 RKNN 部署在 RK3588 NPU 上运行；语音转文字采用 sherpa-onnx

的 RK3588 流式双语语音识别模型；声音分类模型通过 RKNNLite 在本地

运行；声源定位则采用基于麦克风阵列的传统声学算法计算方向。通过本地

化部署，系统减少了对云端网络的依赖，能够更好地满足 AR 头显低延迟、

移动使用和隐私保护的要求。

整体来看，本软件系统并不是多个功能的简单叠加，而是将手语、语音、

导航、声音感知和后视辅助统一接入同一套 AR 交互平台。各模块既相互独

立，便于调试和扩展，又通过多模态融合层和主控 HUD 程序形成统一用户

体验，为听障用户提供实时、直观、可穿戴的辅助交互能力。

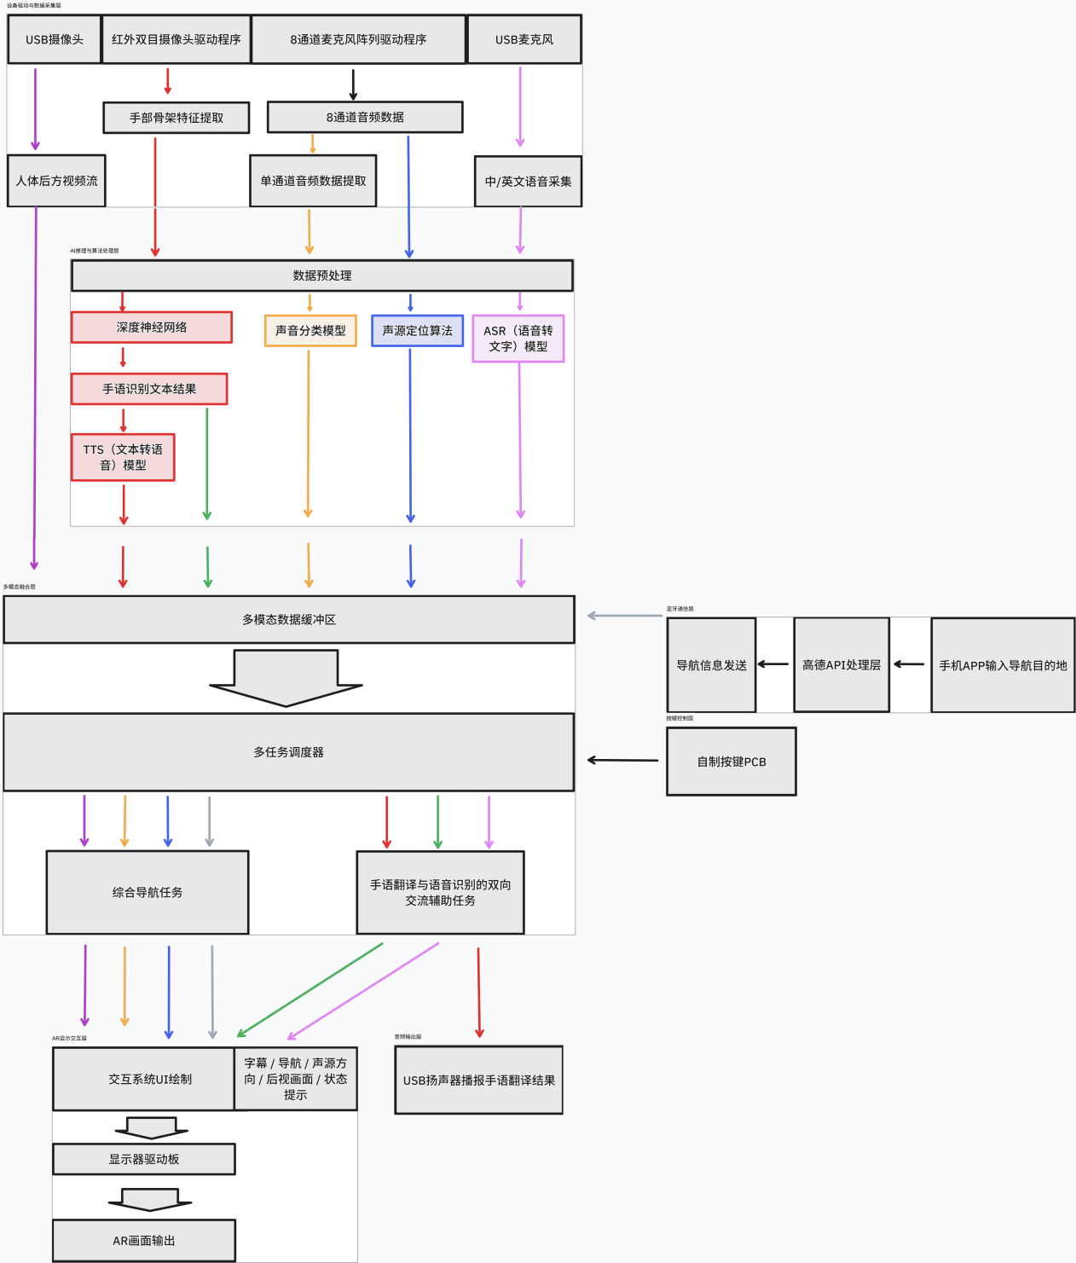
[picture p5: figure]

图 2-3

2.3.2 软件各模块介绍

2.3.2.1 设备驱动与数据采集层

设备驱动与数据采集层位于系统底层，主要负责各类硬件设备的初始化、

数 据读取和基础缓存，是上层算法处理和交互显示的数据来源。该层主要

包括 后置 USB 摄像头采集、红外双目摄像头采集、8 通道麦克风阵列采

集、USB 麦克风采集、蓝牙通信接收以及外部按键 PCB 数据读取等模块。

后置摄像头模块主要用于骑行或通勤场景下的后方环境辅助感知。系统

通过 V4L2 / OpenCV 获取后置摄像头视频流，并以独立线程持续采集，降

低缓冲延迟。仓库介绍中给出的默认配置为 /dev/video21、640×480 分辨率

和 60 fps 默认采集帧率，同时通过设置较小的缓冲区，使后视画面能够以较

低延迟合成到骑行模式界面中。

红外双目摄像头部分采用 Ultraleap Sir170 双目红外相机。该设备面向近

距离手部交互场景，能够输出高精度 3D 手部骨架数据。系统通过 LeapC

获取手部跟踪结果，并在头显跟踪模式下持续接收手部帧，为后续手语识别

提供骨架级结构化输入。与普通 RGB 摄像头相比，该方式不只是获取二维

图像，而是直接获取手部关节点的三维空间坐标，更适合近眼 AR 交互和动

态手语识别。

音频采集部分由 8 通道麦克风阵列和 USB 麦克风共同完成。8 通道麦

克风阵列主要服务于声音雷达功能，用于声音事件分类和声源方向估计；

USB 麦克风主要用于语音转文字，采集较清晰的单通道语音信号。采集到的

多通道音频和单通道语音会分别送入声音雷达服务和 STT 语音识别模块。

蓝牙通信和按键控制也属于系统输入链路。蓝牙模块用于接收手机 APP

发送的导航 JSON 数据，外部按键 PCB 用于实现本地模式切换和功能控制。

采集层得到的图像、骨架、音频、导航和按键数据会根据类型送入 AI 推理

与算法处理层或多模态融合层。

2.3.2.2 AI 推理与算法处理层

AI 推理与算法处理层是系统实现智能感知和声学分析功能的核心部分，

主要包括手语识别、语音转文字、声音分类和声源定位四类功能。该层既包

含基于 RK3588 NPU / RKNN 的模型推理，也包含基于传统阵列信号处理的

声源定位算法。

手语识别由 ultraleap_rknn_live 模块执行。系统首先连接 Ultraleap 设备，

并使用头显跟踪模式持续接收手部帧。当检测到手势动作后，程序将手部关

节点序列整理为模型输入，并调用 sign_rk3588.rknn 在 RK3588 NPU 上进

行推理。该模型输入包含双手、26 个关节点、三维坐标以及位置和速度信息，

时间维统一重采样为 60 帧，最终形成 [1, 6, 60, 26, 2] 的输入张量。这说明

系统的手语识别不是单帧静态姿态分类，而是结合空间结构和时间变化的时

序手语识别。

语音转文字模块基于 sherpa-onnx 生态实现。STT 侧采用 sherpa-onnx-

alsa，模型文件包括 encoder.rknn、decoder.rknn、joiner.rknn 和 tokens.txt。该

模型为 RK3588 流式双语语音识别模型，具备边说边出字、支持中英双语和

离线运行等特点。系统将其集成到 SPEECH TO TEXT 和 HEARING

ASSIST 模式中，用于为听障交流和骑行场景提供实时字幕能力。

声 音 分 类 模 块 由 | sound_radar_service.py | 负 责 ， 使 用

yamnet_rk3588_int8.rknn 和 yamnet_class_map.csv。系统从 8 路麦克风中选

取分类专用通道，重采样至 16 kHz，构建 log-mel spectrogram，并生成 (1,

96, 64, 1) 形状的输入送入 RKNNLite 推理。声音分类并不追求识别所有声

音，而是针对出行安全场景重点识别车喇叭、警示音、狗叫等有提醒意义的

声音事件。

声源定位模块采用纯算法方式实现，不依赖神经网络模型。系统基于 8

通道麦克风阵列采集到的音频数据进行 DOA 方向估计，主要流程包括 48

kHz 采样、使用外圈 6 个通道进行方向估计、300～4000 Hz 带通滤波、

GCC-PHAT 通道间时延估计、SRP-PHAT 空间角度搜索、多通道几何布局计

算以及方向平滑等步骤。系统在 -180°～180° 的角度范围内进行打分，结合

直达声/回声能量比、时间历史和置信度机制抑制反射干扰、瞬时噪声和方向

跳变。

该层的主要输入为 3D 手部骨架数据、单通道语音数据和 8 通道音频

数据，主要输出为手语识别文本、语音识别文本、声音事件类别和声源方向

信息。

2.3.2.3 多模态融合层

多模态融合层是系统软件的核心调度部分，主要负责接收不同模块输出

的数据，并进行统一缓存、状态管理、优先级判断和任务分发。该层包括多

模态数据缓冲区和任务调度器两个关键部分。

多模态数据缓冲区负责暂存来自手语识别、语音转文字、声音分类、声

源定位、后置摄像头、蓝牙导航和按键控制等模块的数据。由于不同模态的

数据更新频率不同，例如后视摄像头持续高帧率刷新，语音识别按语句片段

输出，声源定位按事件和时间窗口更新，导航信息则由手机端按状态变化发

送，因此需要通过数据缓冲区对多源信息进行解耦。

任务调度器负责根据当前系统状态和工作模式决定输出内容。系统可在

导航辅助、听障字幕、手语翻译、声音雷达和后视辅助等模式之间切换。当

系统处于导航或骑行模式时，导航信息、声音雷达结果和后视画面具有较高

优先级；当系统处于交流辅助模式时，ASR 字幕和手语识别结果具有较高优

先级；当声音雷达检测到具有安全意义的声音事件时，系统会结合声音类别

和声源方向，在 AR 画面中给出可视化方向提示。

多模态融合层还负责将不同任务输出到不同终端。需要用户阅读的信息

会送入 AR 显示交互层；需要对外表达的信息会送入音频输出层；需要回传

给手机端的状态信息会送入蓝牙通信层。通过这种统一调度方式，系统避免

了多个功能模块同时输出导致的信息冲突，使最终交互体验更加清晰。

2.3.2.4 导航辅助任务

导航辅助任务由手机 APP 和头显端 HUD 系统协同完成。手机端

Flutter App aura_nav 是导航功能的上游控制中心，主要负责定位、地图搜索、

路线规划、路径缓存和蓝牙数据发送；头显端则负责接收导航 JSON 数据，

并将导航结果绘制为适合近眼显示的 HUD 界面。

手机端使用 amap_flutter_map / amap_flutter_base 提供高德地图能力，使

用 Geolocator 获取高精度位置，使用 permission_handler 处理 Android 权

限，并通过自定义 BluetoothTransport 与头显端通信。在定位方面，APP 采

用持续位置流和周期性刷新相结合的方式，并使用导航级定位精度。在路径

规划方面，APP 请求高德骑行路径接口，解析每个 step 的 polyline，合并

为完整路线，并建立 _CachedRoute 以便后续快速投影和重路由。

为了提高导航稳定性，APP 不会在每次位置更新时都重新请求路线，而

是先将当前位置投影到当前路线折线段上，计算已行进距离、当前位置到路

线的最短距离，并在偏离路线超过一定阈值且连续命中后触发重路由。该机

制可以减少无意义网络请求和路线抖动，使头显端收到的下一步动作、剩余

距离和总距离更加稳定。

蓝牙通信方面，手机端通过 bluetooth_transport.dart 封装蓝牙能力，头显

端则在 ar_app1_hud.cpp 中开启 Bluetooth RFCOMM 服务，按行接收 JSON

数据。手机端向头显同步当前经纬度、目的地经纬度、目的地名称、下一步

动作、到下一步动作的距离、剩余距离、总距离和全路径 polyline 等信息，

并通过避免重复发送相同 payload 来减少蓝牙带宽浪费。

头显端导航 UI 不是传统二维地图平移，而是面向近眼显示设计的简洁

HUD。界面包含前方主引导路径、路线高亮、小地图总览、转向箭头、剩余

距离进度条以及到达态和待机态动画。系统还对方向、距离和状态切换进行

平滑处理，以减少箭头跳动和界面抖动。

2.3.2.5 双向交流辅助任务

双向交流辅助任务面向听障用户与普通人之间的日常沟通，主要包括“语

音转文字显示”和“手语转语音输出”两条功能链路。

在语音转文字链路中，系统通过 USB 麦克风采集外界语音，并调用

sherpa-onnx STT 模型进行流式识别。识别结果不会只输出到终端日志，而是

被整合到系统的 SPEECH TO TEXT 和 HEARING ASSIST 模式中，最终以

实时字幕形式显示在 AR 画面中，帮助听障用户理解他人讲话内容。

在手语转语音链路中，系统通过 Ultraleap Sir170 获取手部 3D 骨架序

列，并调用自主搭建和训练的深度学习神经网络手语识别模型输出手语文本。

当前模型具备基础词汇表达能力，识别结果可以送入 AR UI 进行文字显示，

也可以进一步送入 TTS 线程进行语音合成，实现“手语输入 → 语音输出”

的交流链路。

TTS 文字转语音基于 sherpa-onnx 离线语音合成链路实现。系统使用

sign_translate_tts_service.py 作为常驻服务进行请求-响应式合成；当常驻服

务不可用时，可回退到 sherpa-onnx-offline-tts 命令行方式直接合成。该设计

支持服务预热、语音缓存、重复播报去重和多设备播放尝试，有助于减少模

型冷启动延迟，并提高音频设备适配能力。

2.3.2.6 声音雷达任务

声音雷达任务是本系统面向出行安全的重要功能之一。该任务将 8 通道

麦克风阵列采集、声音事件分类、声源方向估计、时间平滑、异常抑制和 HUD

方向可视化串联成完整链路，使听障用户能够以可视方式感知周围重要声音

来源。

声音雷达首先通过 8 通道麦克风阵列采集环境声音。声音分类模型用于

判断当前声音是否属于具有安全提醒意义的类别，例如车喇叭、警示音、狗

叫等。声源定位算法则进一步估计声音来自哪个方向。该设计形成了“先判断

是什么声音，再判断声音从哪里来”的双阶段处理方式，而不是单纯依赖神经

网络或简单音量阈值触发。

在方向估计方面，系统使用 GCC-PHAT 估计通道间时延，并使用 SRP-

PHAT 在角度空间内搜索最优方向。为了抑制环境反射和瞬时噪声，系统还

加入了直达声/回声比过滤、稳定 cluster 判断、冷启动确认、大角度突变确

认、历史方向平滑和输出节流等机制。最终输出的方向不会随着每帧瞬时最

大值跳动，而是形成对用户更有意义的稳定方向提示。

HUD 侧接收到声音雷达事件后，会进一步进行 UI 级平滑。每个声音目

标包含目标角度和显示角度，系统通过弹簧-阻尼模型推进显示角度，限制角

速度上限，并根据类别显示不同样式。这样，声音雷达不只是后台检测日志，

而是能够在 AR 画面中形成直观的空间提示，将“看不见的声音”转化为用户

可理解的方向信息。

2.3.2.7 后视辅助任务

后视辅助任务用于为骑行、通勤和行走场景提供实时后方视觉信息。系

统通过后置摄像头采集用户身后的广角画面，并将其与导航信息、声音雷达

提示共同合成到骑行模式界面中，帮助用户减少回头观察次数，提高后方态

势感知能力。

后视摄像头模块采用 V4L2 / OpenCV 取流方式，并通过独立线程持续

采集视频帧。为了减少显示延迟，系统设置较小的缓冲区，使最新帧能够尽

快进入 HUD 合成流程。多模态融合层根据当前模式决定是否显示后视画面。

在骑行模式下，后视图像可作为小窗口叠加到 AR HUD 中，并与导航箭头

和声音雷达方向提示共同构成安全辅助界面。

2.3.2.8 AR 显示交互层

AR 显示交互层是系统的主要视觉输出模块，负责将多模态融合层分发

的内容绘制成适合近眼显示的 HUD 界面。该层不仅负责简单图形绘制，还

承担光学校正、双目渲染、UI 平滑和模式界面切换等任务。

在底层显示链路上，系统直接访问 /dev/dri/card0，使用 DRM / GBM 完

成缓冲区管理，使用 EGL / OpenGL ES 进行图形渲染，并使用 NanoVG 绘

制文字、线条、图标、圆角、描边和动画等 HUD 元素。该设计绕开桌面合

成器，能够减少不必要的显示链路开销，降低图像抖动，更适合固定功能的

AR 头显运行时。

在光学校正方面，系统读取 calibration.json 中的标定参数，生成左右眼

UV 反畸变网格。渲染时，系统根据每只眼的标定参数对逻辑 UI 进行重映

射，使画面经过近眼镜片后在人眼中呈现为正常几何形状。同时，系统还考

虑左右眼的光学平面角度、眼点位置、显示平面剪切和运行时汇聚微调参数，

使双目显示更加稳定。

在 UI 内容方面，AR 显示交互层需要同时承载导航提示、语音字幕、

手语识别文本、声音雷达方向、后视画面和系统状态。为了避免信息过载，

系统采用面向近眼显示的简洁界面设计，将“下一步动作”“方向提示”“字幕文

本”等关键信息放在用户更容易注意到的位置，同时通过动画和平滑过渡降

低视觉突变。

2.3.2.9 音频输出层

音频输出层主要负责语音合成和播放控制，用于将手语识别结果或系统

提示信息转换为可听声音。该层以 TTS 文字转语音模块为核心，通过 USB

扬声器进行音频输出。

当手语识别模块输出文本后，多模态融合层会根据当前任务状态判断是

否 需 要 语 音 播 报 。 如 果 需 要 播 报 ， 则 将 文 本 发 送 给

sign_translate_tts_service.py 常驻服务进行离线语音合成。若常驻服务不可用，

系统可回退到 sherpa-onnx-offline-tts 命令行方式生成语音。系统还通过缓存

机制、重复播报去重和播放设备自动检测，提高语音输出效率和部署稳定性。

音频输出层使系统具备“手语输入 → 文字识别 → 语音输出”的完整表

达能力。对于不懂手语的交流对象，USB 扬声器播放出的语音能够直接表达

听障用户的手语内容，从而提升沟通效率。

2.3.2.10 蓝牙通信层

蓝牙通信层用于连接手机 APP 与头显端，是导航信息进入 AR 头显的

重要桥梁。手机端通过 bluetooth_transport.dart 封装蓝牙能力，并通过

MethodChannel 调用 Android 原生蓝牙接口，支持蓝牙状态判断、已配对设

备列表获取、ELF2 板端地址选择、连接断开以及 JSON 负载发送。

头显端在 ar_app1_hud.cpp 中开启 Bluetooth RFCOMM 服务，注册

SDP 服务描述，并通过 socket 按行接收 JSON 数据。接收到的数据包括当

前经纬度、目的地经纬度、目的地名称、下一步动作、剩余距离、总距离和

完整路径 polyline 等。解析后的导航数据进入多模态融合层，并最终由 AR

显示交互层绘制成 HUD 导航界面。

2.3.2.11 按键控制层

按键控制层用于处理自制外部按键 PCB 发送的本地控制信息，为用户

提供不依赖手机 APP 的快速交互方式。该模块主要承担模式切换、功能确

认、显示切换和任务启停等控制功能。

在佩戴状态下，用户不一定方便频繁操作手机 APP，因此外部按键 PCB

可以作为快速控制入口。例如，用户可通过按键切换导航辅助模式、语音字

幕模式、手语翻译模式、声音雷达模式或后视辅助模式。按键数据经过解析

后进入多模态融合层，由任务调度器统一处理，避免不同任务之间发生冲突。

第三部分 完成情况及性能参数

3.1 整体介绍

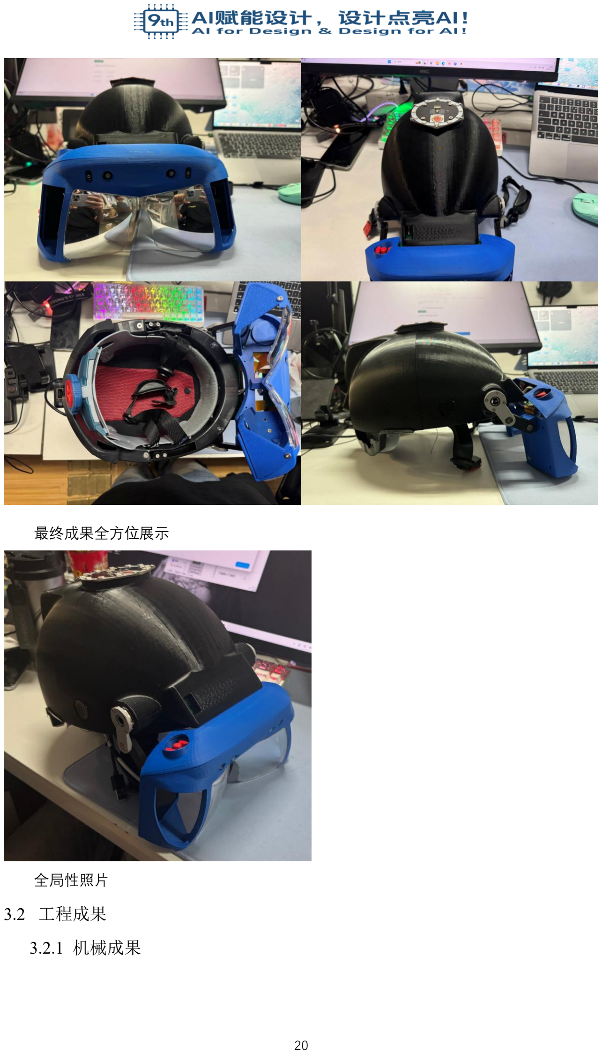
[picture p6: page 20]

最终成果全方位展示

全局性照片

3.2 工程成果

3.2.1 机械成果

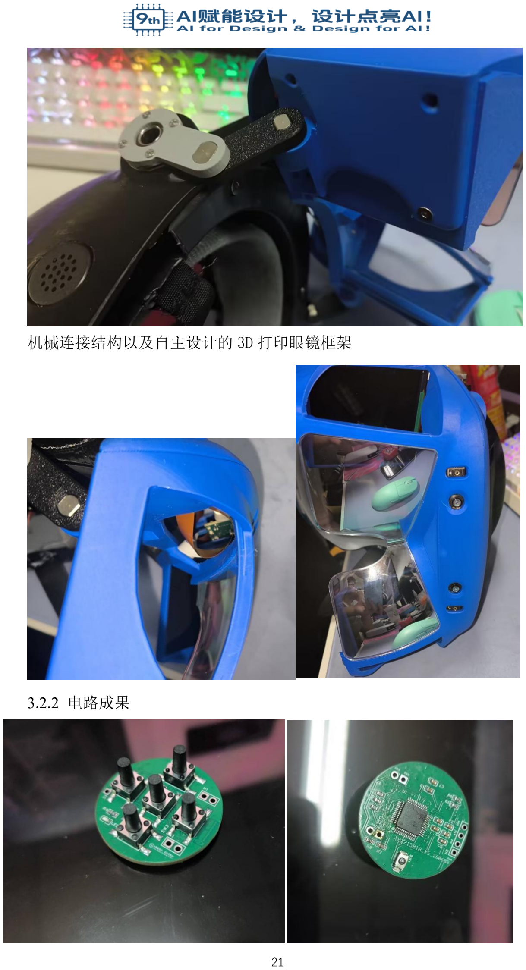
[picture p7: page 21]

机械连接结构以及自主设计的 3D 打印眼镜框架

3.2.2 电路成果

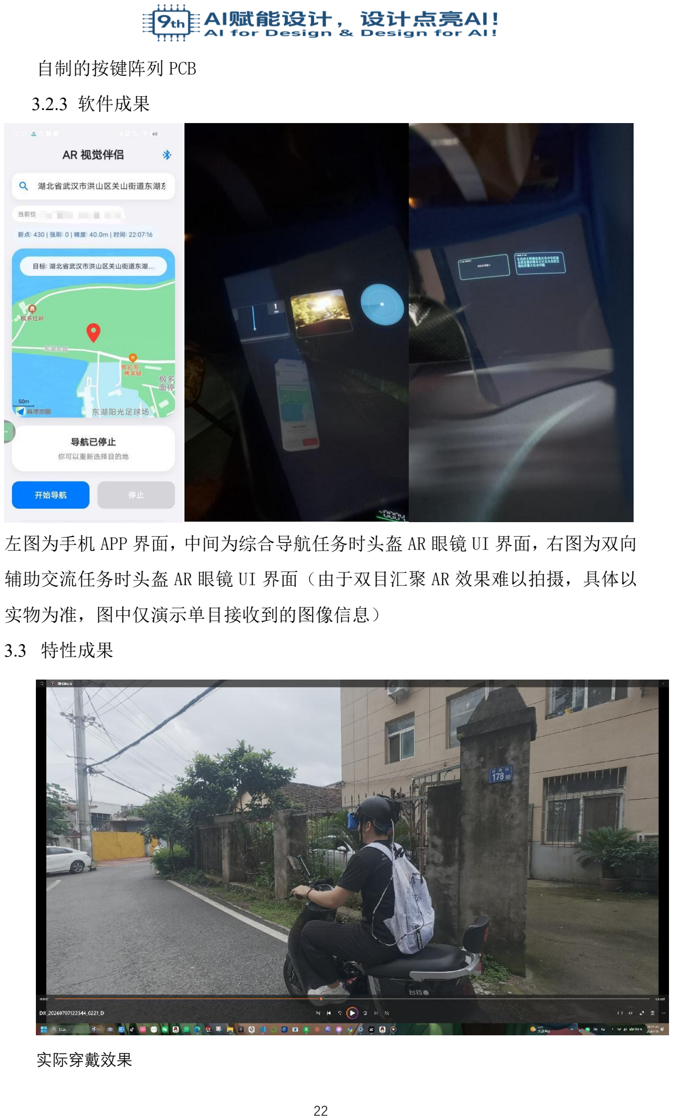
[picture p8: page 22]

自制的按键阵列 PCB

3.2.3 软件成果

左图为手机 APP 界面，中间为综合导航任务时头盔 AR 眼镜 UI 界面，右图为双向

辅助交流任务时头盔 AR 眼镜 UI 界面（由于双目汇聚 AR 效果难以拍摄，具体以

实物为准，图中仅演示单目接收到的图像信息）

3.3 特性成果

实际穿戴效果

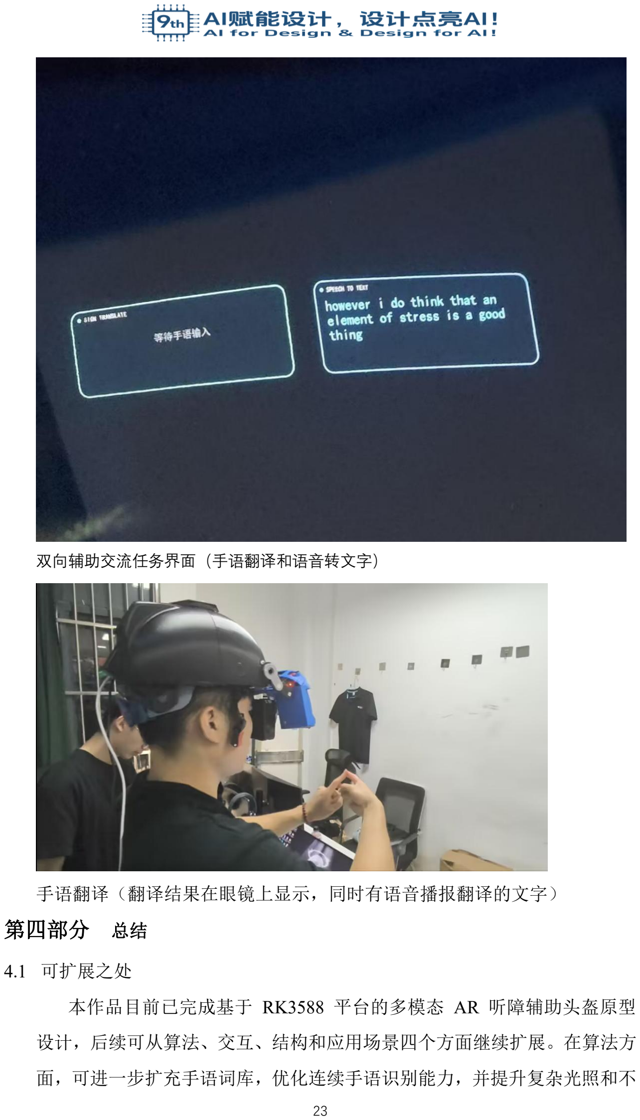
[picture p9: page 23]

双向辅助交流任务界面（手语翻译和语音转文字）

手语翻译（翻译结果在眼镜上显示，同时有语音播报翻译的文字） 第四部分 总结

4.1 可扩展之处

本作品目前已完成基于 RK3588 平台的多模态 AR 听障辅助头盔原型

设计，后续可从算法、交互、结构和应用场景四个方面继续扩展。在算法方

面，可进一步扩充手语词库，优化连续手语识别能力，并提升复杂光照和不

同佩戴姿态下的识别稳定性；语音识别方面可加入更强的降噪和语音增强算

法，提高嘈杂环境下的字幕准确率；声音雷达方面可继续优化声源定位精度

和多声源场景下的判断能力。在交互方面，可完善 AR HUD 的信息优先级、

图标化提示和动画过渡效果，降低用户认知负担。在结构方面，可进一步减

轻整机重量、优化散热和续航，并提升佩戴舒适性。未来该系统还可扩展至

骑行安全、工业巡检、无障碍导览、公共服务辅助和应急提醒等场景。

4.2 心得体会

在研发过程中，我们经历了方案调整、模型训练效果不理想、多模块联

调困难等问题。通过持续迭代和系统调试，最终完成了较高集成度的作品原

型。本作品面向听障用户在日常交流、出行导航和环境感知中的实际需求，

完成了一套从硬件结构、嵌入式软件、AI 模型部署到 AR 显示交互的完整

系统设计。相比单一功能演示类项目，本作品更强调多模块协同和真实可穿

戴场景下的系统集成。整个开发过程使我们认识到，智能硬件作品的难点不

仅在于某一个算法或传感器，而在于如何将感知、计算、显示、交互、电源

和结构设计整合为一个稳定可用的整体。

在硬件和结构设计方面，我们没有采用普通头盔外挂模块的方式，而是

自主设计了 3D 打印头盔本体和 AR 眼镜支架。ELF2（RK3588 开发板）被

内嵌在头盔内部，扬声器出声口、麦克风声孔、摄像头通道和显示支架均根

据实际功能需求进行定制设计，线缆也尽可能采用内走线方式。为了优化模

块安装位置、线缆路径、功能开孔和维修空间，我们进行了多轮结构修改和

打印验证，累计产生了两框 3D 打印迭代件与废料，这也让我们深刻体会到

机械结构设计对整机完成度的重要性。

在软件开发方面，我们逐步形成了以 AR 主控程序为核心的分层架构。

系统并不是简单运行多个独立程序，而是通过统一的 HUD 运行时对导航、

手语识别、语音识别、声音雷达、后视摄像头和音频播报结果进行集中管理，

使各功能能够在同一套 AR 界面中协同呈现。近眼显示场景下，信息不能简

单堆叠，还需要考虑显示区域、文字大小、视觉遮挡、刷新延迟和用户注意

力分配，因此 AR UI 的设计必须兼顾功能性和可读性。

在算法部署方面，我们充分利用 RK3588 的边缘计算能力，将手语识别、

语音转文字、声音分类等模型尽量部署在本地运行，同时采用传统阵列信号

处理算法完成声源定位。项目中 STT/TTS 基于 sherpa-onnx 实现本地语音

识别与合成，手语识别和声音分类模型通过 RKNN/RKNNLite 部署在 RK3588

平台上，其中手语识别模型为我们自主搭建的 ST-GCN 和 MS-TCN 深度学习

网络。通过该过程，我们对深度学习模型训练、嵌入式 AI 模型转换、NPU

推理加速和实际运行延迟有了更深入的理解。

通过本次作品开发，我们不仅掌握了 RK3588 平台、NPU 模型部署、AR

近眼显示、Flutter 手机端通信、音频信号处理和 3D 打印结构设计等技术，

也锻炼了完整系统工程的设计能力。后续我们将继续围绕识别准确率、显示

舒适性、整机轻量化、续航能力和真实场景测试进行优化，使作品进一步接

近实际应用产品形态。

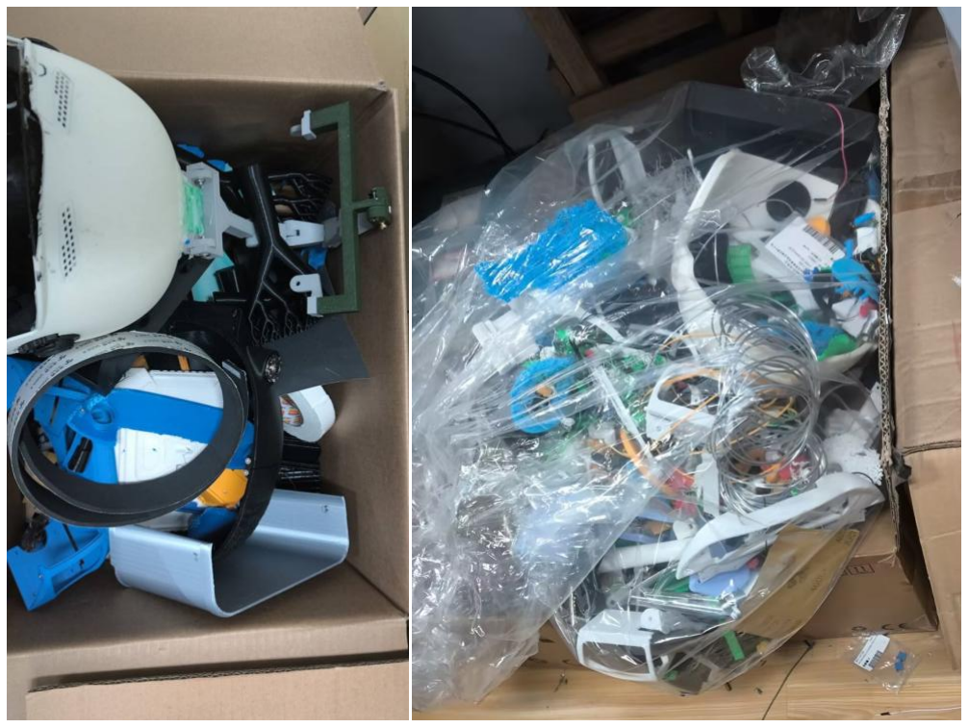
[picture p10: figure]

图为 3D 打印废料和迭代产品

第五部分 参考文献

按照标准格式，限 20 篇以内。

[1] Rockchip-linux. RKNN-Toolkit2: Rockchip NPU Model Conversion, Inference and

Evaluation Toolkit[EB/OL]. GitHub.

[2] K2-FSA.sherpa-onnx Documentation[EB/OL].
[3] K2-FSA.sherpa-onnx:Speech-to-text | and | Text-to-speech | Toolkit

[EB/OL]. GitHub.

[4] Ultraleap. LeapC Guide[EB/OL]. Ultraleap Documentation.TensorFlow.

Sound Classification with YAMNet[EB/OL]. TensorFlow Hub.

[5] Khronos Group. OpenGL and OpenGL ES Reference Pages[EB/OL]. Khronos

Registry.

[6] Memonen M. NanoVG: Antialiased 2D Vector Drawing Library for

OpenGL[EB/OL]. GitHub.

[7] 高德开放平台相关开发者 .amap_flutter_map Package Documentation

[EB/OL]. pub.dev.

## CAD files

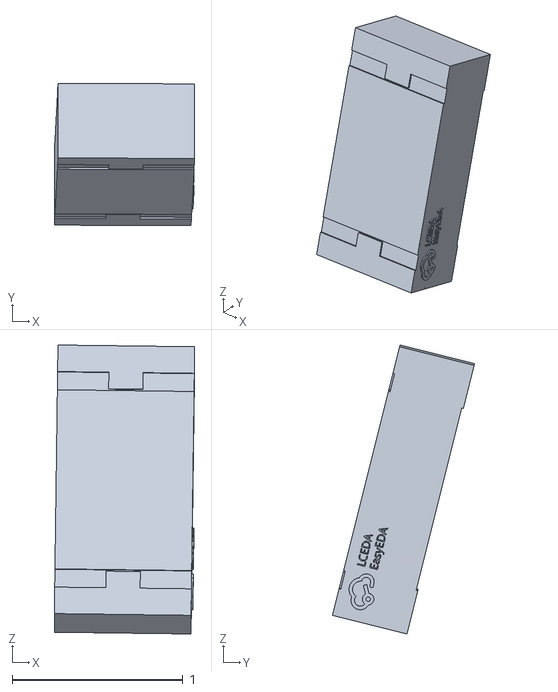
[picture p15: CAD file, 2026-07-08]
3D Model/头盔装配 - 按键装配体-1 按键模块-1 按键模块(2)-1 R1~R0603~R0603~OrpE-4 R0603~R0603~OrpE-1.STL
0.821 x 0.832 x 1.69

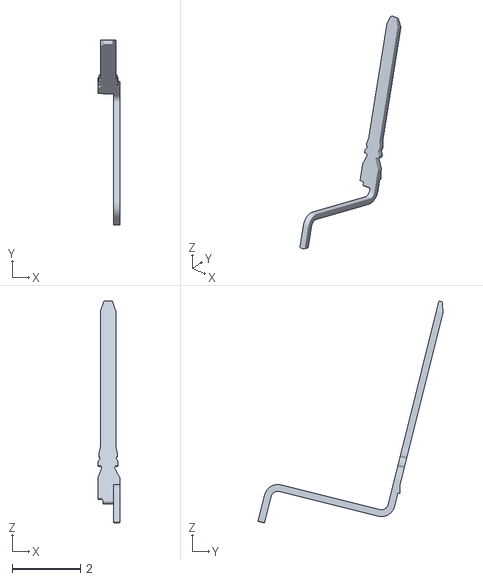
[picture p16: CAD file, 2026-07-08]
3D Model/头盔装配 - ELF 2 V1.2-1 ELF 2 V1.2(2)-1 Free-Models__et_RGB16777215-1 HDMI_socket_large_pin-7.STL
0.65 x 5.43 x 6.51

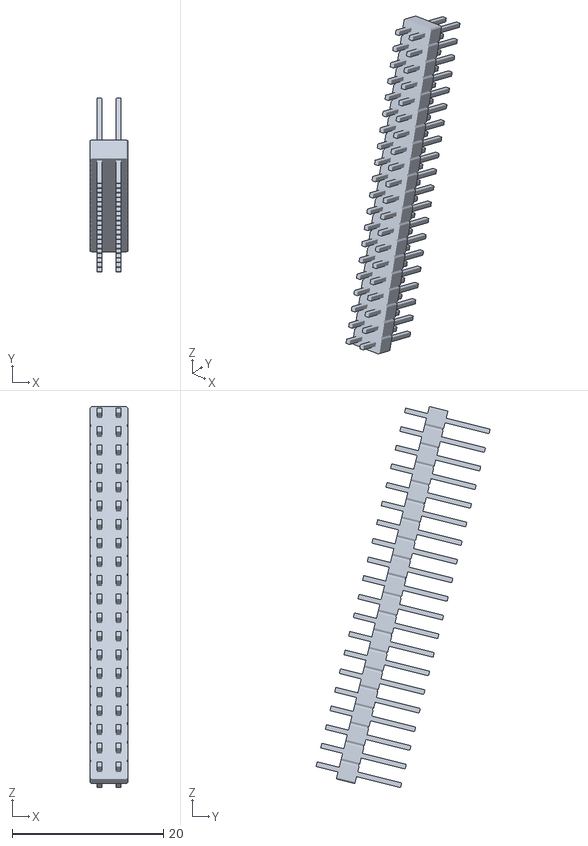
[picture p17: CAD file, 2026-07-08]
3D Model/头盔装配 - ELF 2 V1.2-1 ELF 2 V1.2(2)-1 P26-1 1120201246-_________2X20P-2.54-1.STL
5.00 x 23.0 x 50.4

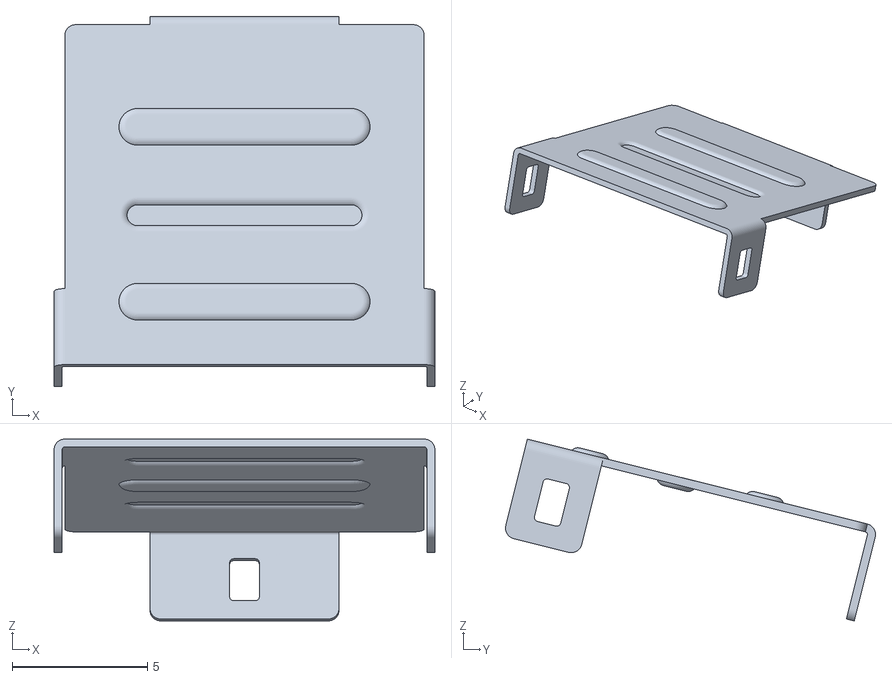
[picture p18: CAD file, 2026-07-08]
3D Model/头盔装配 - ELF 2 V1.2-1 ELF 2 V1.2(2)-1 P22-1 61400826021-1 Shielding_2-1.STL
14.1 x 13.7 x 6.74

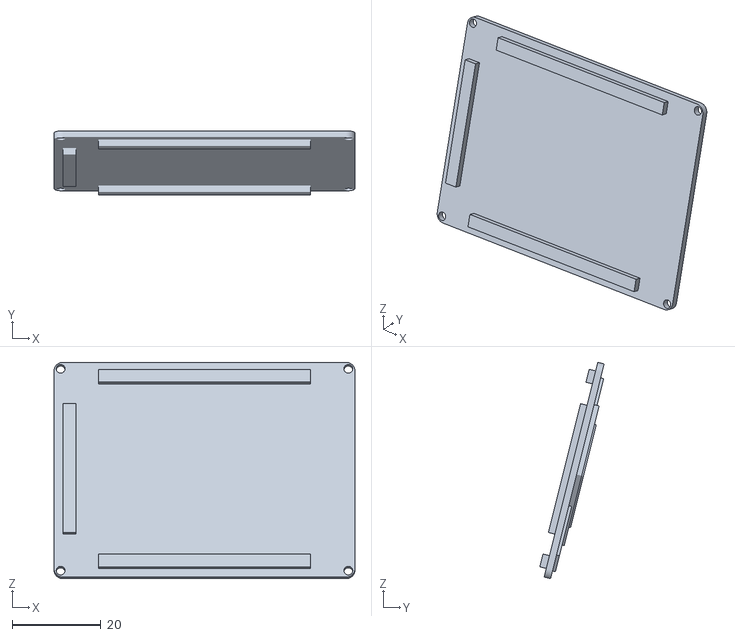
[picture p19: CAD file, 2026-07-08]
3D Model/头盔装配 - ELF 2 V1.2-1 RK3588主控-1.STL
68.0 x 14.5 x 48.9

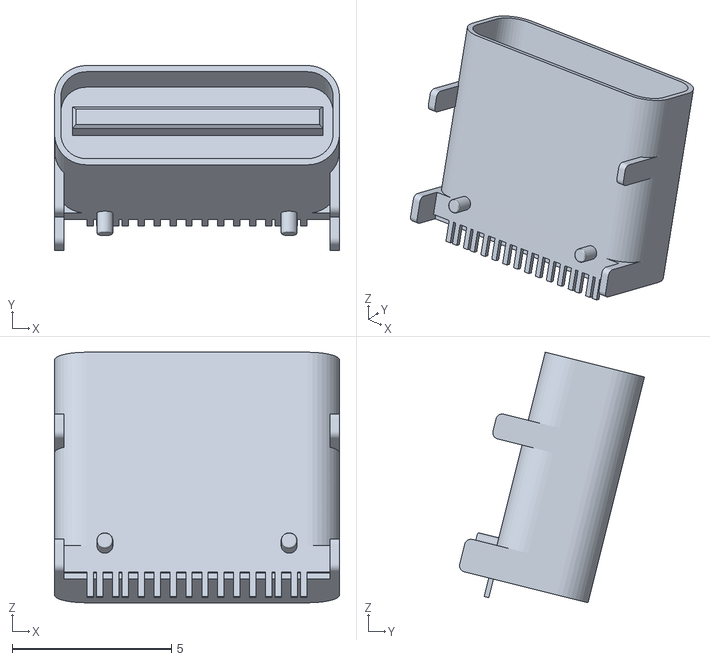
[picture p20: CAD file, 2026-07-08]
3D Model/头盔装配 - ELF 2 V1.2-1 2031-TYPE__-1.STL
8.94 x 5.80 x 7.86

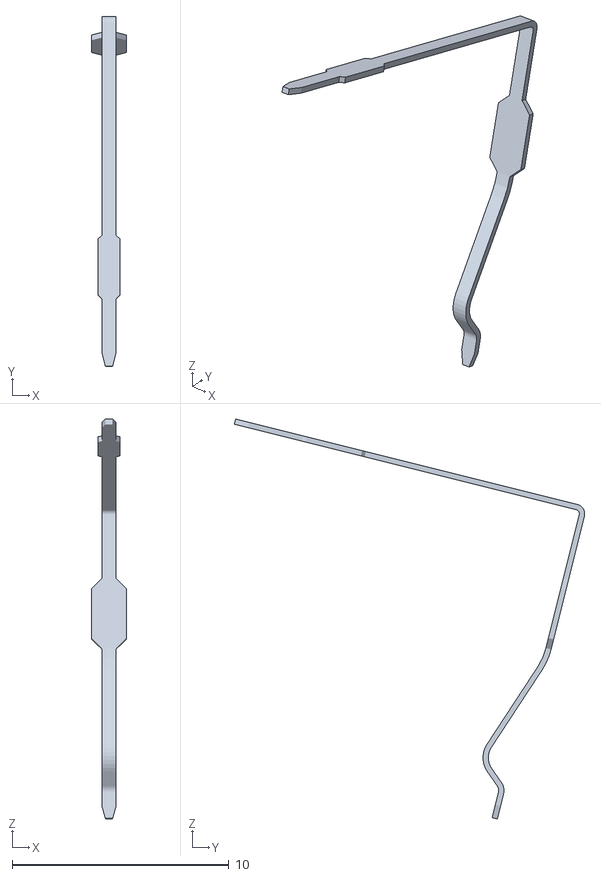
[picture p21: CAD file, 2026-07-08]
3D Model/头盔装配 - ELF 2 V1.2-1 ELF 2 V1.2(2)-1 P22-1 61400826021-1 Pin_2-1.STL
1.60 x 16.2 x 18.5

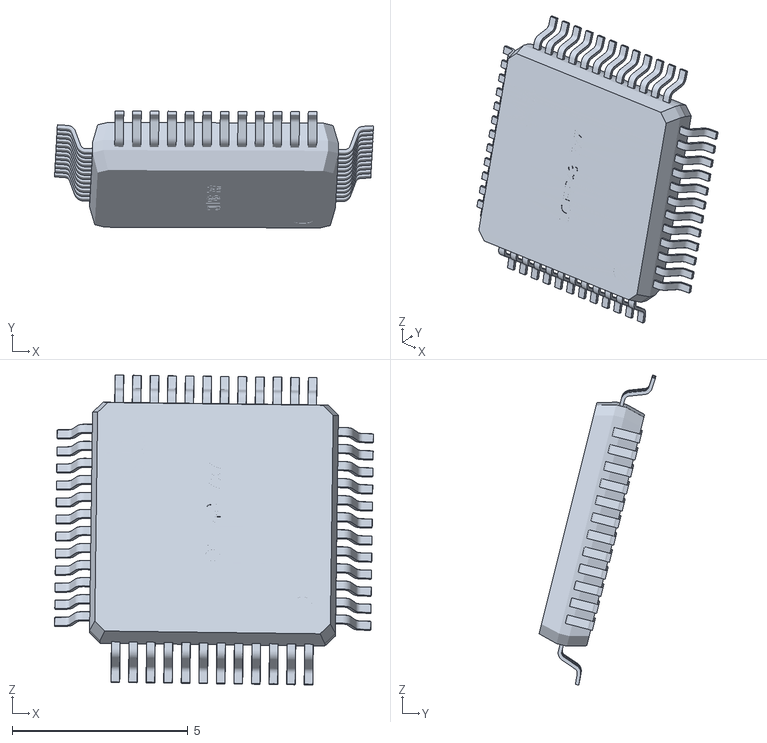
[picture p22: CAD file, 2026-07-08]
3D Model/头盔装配 - 按键装配体-1 按键模块-1 按键模块(2)-1 U1~LQFP-48_L7.0__QFP-48_L7.0-W7.0-H1.4-LS9.0-P0.50~OrpE-1.STL
9.07 x 3.32 x 8.82

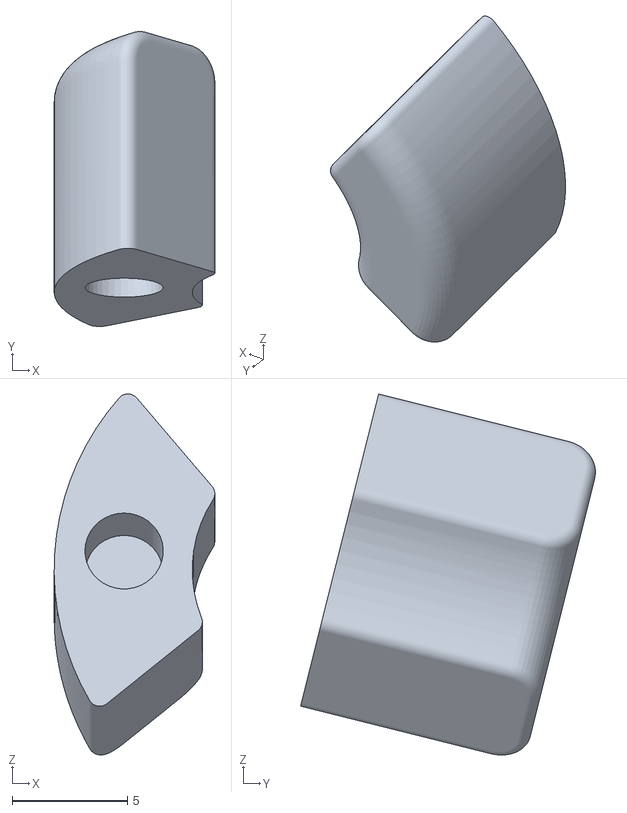
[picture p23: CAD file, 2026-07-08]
3D Model/头盔装配 - 按键装配体-1 外围-1.STL
6.98 x 12.8 x 15.7

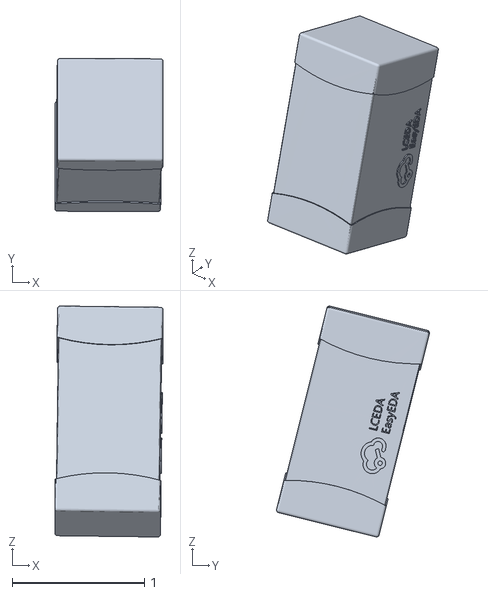
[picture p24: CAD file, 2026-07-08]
3D Model/头盔装配 - 按键装配体-1 按键模块-1 按键模块(2)-1 C1~C0603~C0603___OrpE-6 C0603~C0603_L1.6-W0.8-H0.8~OrpE-1.STL
0.82 x 1.16 x 1.75

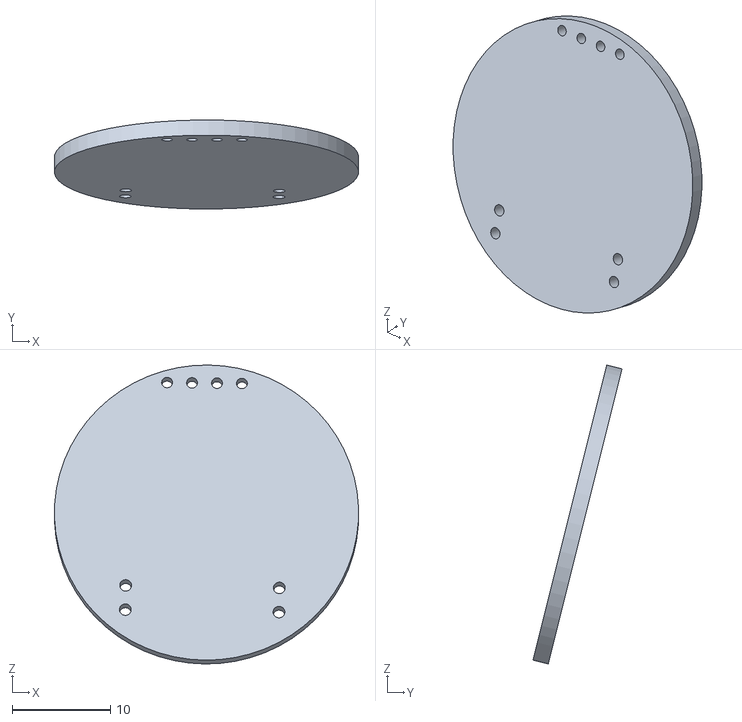
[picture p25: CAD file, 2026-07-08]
3D Model/头盔装配 - 按键装配体-1 按键模块-1 按键模块(2)-1 Board~OrpE-1.STL
30.9 x 9.06 x 30.4

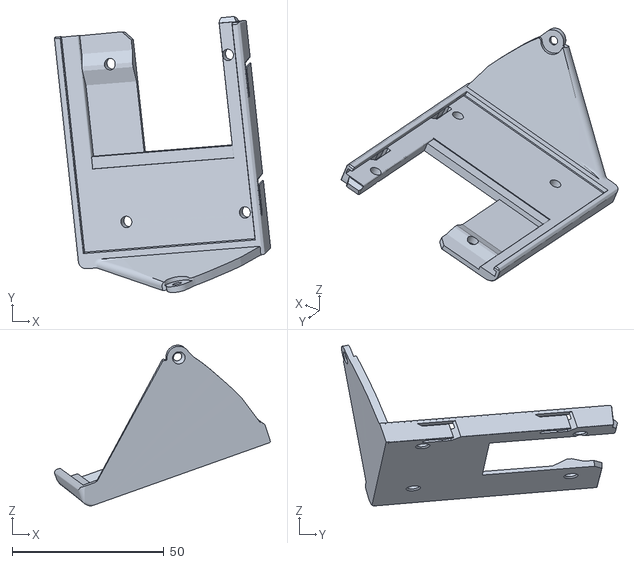
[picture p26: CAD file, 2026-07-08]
3D Model/头盔装配 - 眼镜整体装配体-1 显示固定（装-2）-眼镜上的-1 显示固定-2-眼镜上的-1.STL
71.1 x 90.8 x 52.9

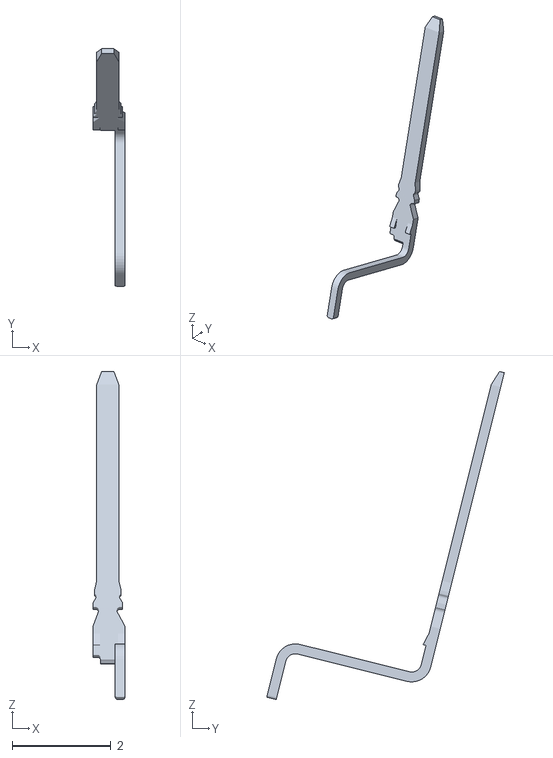
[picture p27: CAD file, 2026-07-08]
3D Model/头盔装配 - ELF 2 V1.2-1 ELF 2 V1.2(2)-1 Free-Models__et_RGB16777215-1 HDMI_socket_small_pin-1.STL
0.65 x 4.82 x 6.65

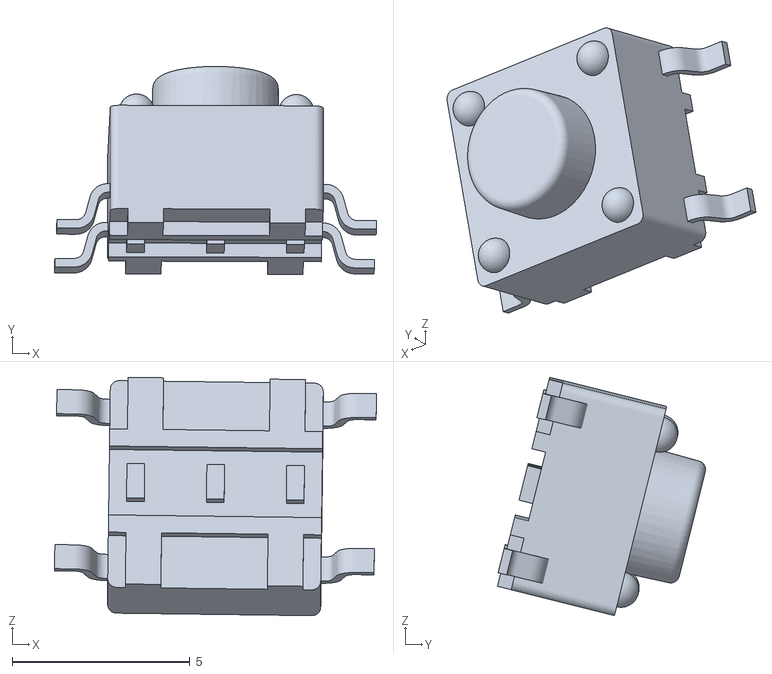
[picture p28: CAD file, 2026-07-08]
3D Model/头盔装配 - 按键装配体-1 按键模块-1 按键模块(2)-1 SW2~KEY-SMD_4P-__SMD_4P-L6.0-W6.0-H5.0-LS10.0-P4.5~OrpE-1_4.STL
9.07 x 5.86 x 6.71

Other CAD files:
3D Model/头盔装配 - ELF 2 V1.2-1 ELF 2 V1.2(2)-1 Free-Models__et_RGB16777215-1 HDMI_socket_large_pin-4.STL
3D Model/头盔装配 - ELF 2 V1.2-1 ELF 2 V1.2(2)-1 P22-1 61400826021-1 Pin_1-3.STL
3D Model/头盔装配 - 眼镜整体装配体-1 显示固定（装-2）-眼镜上的-1 显示器1-眼镜上的-1.STL
3D Model/头盔装配 - 按键装配体-1 按键模块-1 按键模块(2)-1 C1~C0603~C0603___OrpE-3 C0603~C0603_L1.6-W0.8-H0.8~OrpE-1.STL
3D Model/头盔装配 - ELF 2 V1.2-1 Board~1hJp-2.STL
3D Model/头盔装配 - ELF 2 V1.2-1 ELF 2 V1.2(2)-1 Free-Models__et_RGB16777215-1 HDMI_socket_large_pin-1.STL
3D Model/头盔装配 - ELF 2 V1.2-1 ELF 2 V1.2(2)-1 Free-Models__et_RGB16777215-1 HDMI_socket_large_pin-2.STL
3D Model/头盔装配 - ELF 2 V1.2-1 ELF 2 V1.2(2)-1 Free-Models__et_RGB16777215-1 HDMI_socket_large_pin-3.STL
3D Model/头盔装配 - ELF 2 V1.2-1 ELF 2 V1.2(2)-1 Free-Models__et_RGB16777215-1 HDMI_socket_large_pin-5.STL
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

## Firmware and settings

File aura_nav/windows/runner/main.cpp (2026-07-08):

#include <flutter/dart_project.h>
#include <flutter/flutter_view_controller.h>
#include <windows.h>

#include "flutter_window.h"
#include "utils.h"

int APIENTRY wWinMain(_In_ HINSTANCE instance, _In_opt_ HINSTANCE prev,
                      _In_ wchar_t *command_line, _In_ int show_command) {
  // Attach to console when present (e.g., 'flutter run') or create a
  // new console when running with a debugger.
  if (!::AttachConsole(ATTACH_PARENT_PROCESS) && ::IsDebuggerPresent()) {
    CreateAndAttachConsole();
  }

  // Initialize COM, so that it is available for use in the library and/or
  // plugins.
  ::CoInitializeEx(nullptr, COINIT_APARTMENTTHREADED);

  flutter::DartProject project(L"data");

  std::vector<std::string> command_line_arguments =
      GetCommandLineArguments();

  project.set_dart_entrypoint_arguments(std::move(command_line_arguments));

  FlutterWindow window(project);
  Win32Window::Point origin(10, 10);
  Win32Window::Size size(1280, 720);
  if (!window.Create(L"aura_nav", origin, size)) {
    return EXIT_FAILURE;
  }
  window.SetQuitOnClose(true);

  ::MSG msg;
  while (::GetMessage(&msg, nullptr, 0, 0)) {
    ::TranslateMessage(&msg);
    ::DispatchMessage(&msg);
  }

  ::CoUninitialize();
  return EXIT_SUCCESS;
}

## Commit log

2026-07-08 主体代码
    [yamnet_class_map.csv]
2026-07-08 Add 3D Model
    [头盔装配 - ELF 2 V1.2-1 2031-TYPE__-1.STL, 头盔装配 - ELF 2 V1.2-1 Board~1hJp-2.STL, 头盔装配 - ELF 2 V1.2-1 ELF 2 V1.2(2)-1 Free-Models__et_RGB16777215-1 HDMI_socket_larg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]
2026-07-08 增加手机应用源码、设计文档、演示视频
2026-07-08 添加手语识别模型训练代码和RKNN转换脚本
